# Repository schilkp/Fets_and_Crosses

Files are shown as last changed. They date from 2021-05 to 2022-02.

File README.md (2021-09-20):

# Fets and Crosses
### Philipp Schilk

An implementation of the classic Tic-Tac-Toe / Knots and Crosses game
built entirely from 2458 discrete transistors.

Why? *Because.*

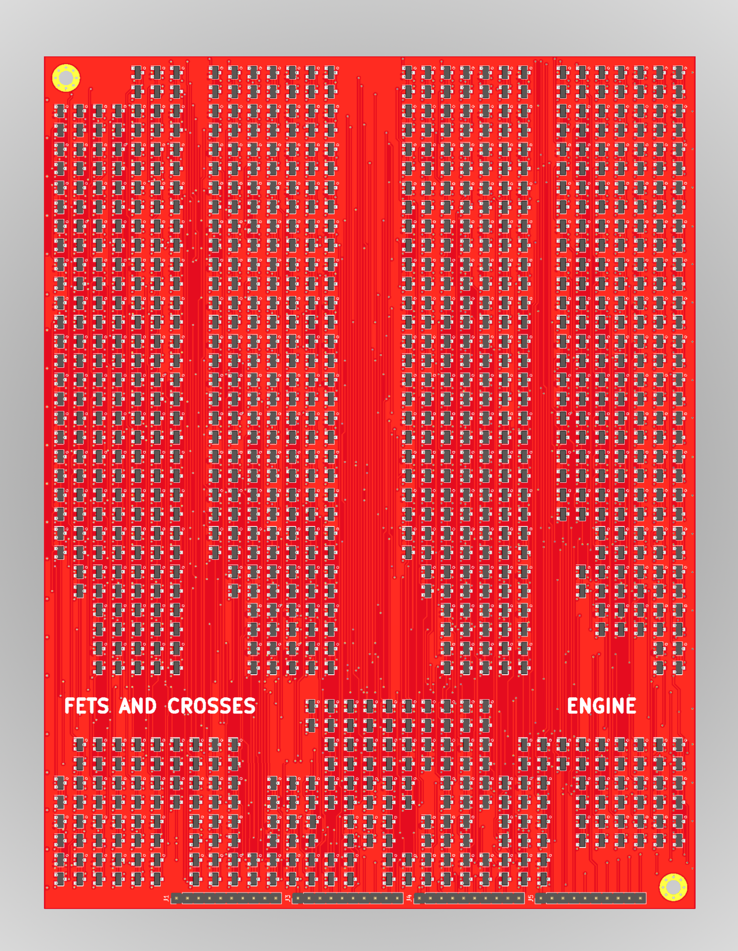
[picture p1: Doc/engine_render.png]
Engine Render


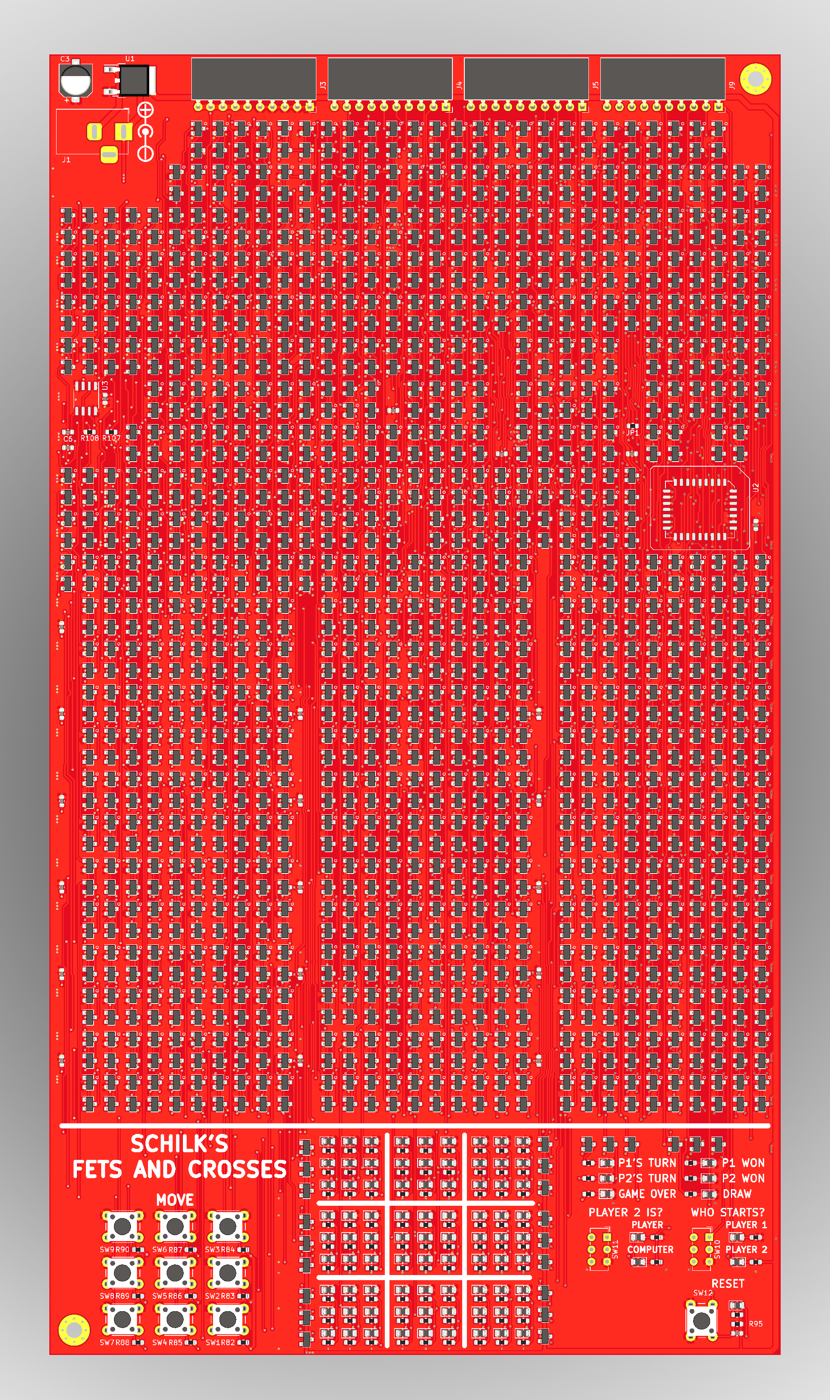
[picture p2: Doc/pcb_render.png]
PCB Render


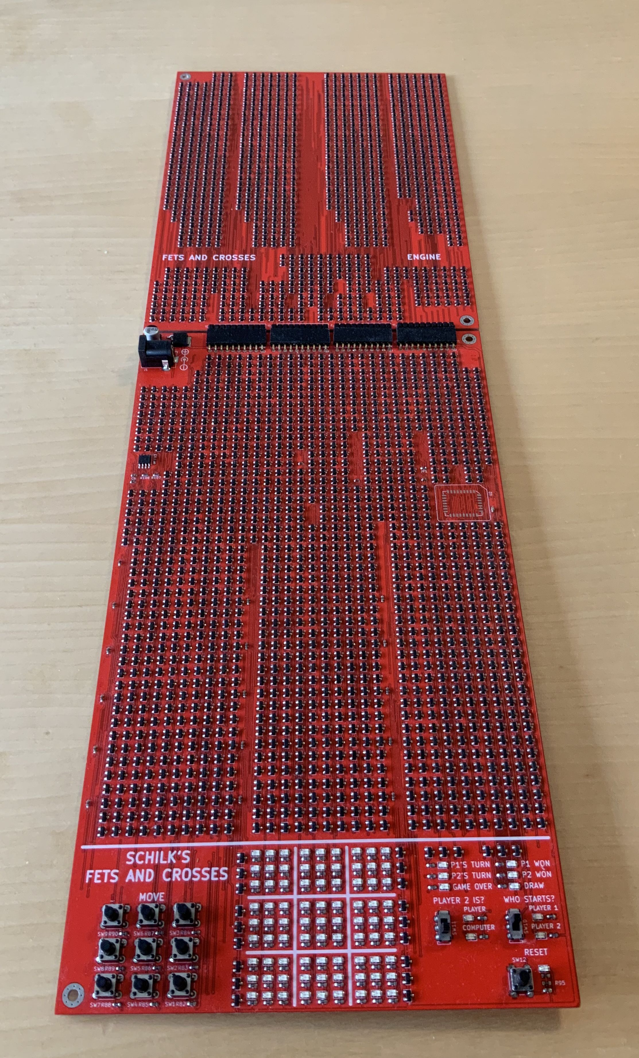
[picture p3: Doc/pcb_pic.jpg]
Full PCB Picture


## Features
- Players vs Player and Player vs Computer with engine fully implemented in transistors.
- Win-State and End-State detection
- Enforces game rules (prevents illegal moves)
- Shiny LEDs

## Release & Schematic viewing
See [Github releases](https://wwww.github.com/TheSchilk/Fets_and_Crosses/releases/) for all production files, schematics, etc...

Although the schematic is included in PDF form, it is recommended to view the schematic in KiCad directly.

## Implementation Details

All logic implemented in standard CMOS logic using discrete transistors.

The engine opponent is also implemented in logic on a seperate PCB, but can be substituted
with a ROM IC on the main IC.

JP1 has to be added when using the ROM IC, and removed when using the engine PCB.

## Overview

**Logisim:**  
	Logic Simulation.
	Download LogiSim at [cburch.com](http://www.cburch.com/logisim/).  
	
**Scripts:**  
	Various python scripts to test different engine designs and generate ROM contents.  

**ROM:**  
	Generated ROM files.  
	
**ECAD:**  
    All KiCad projects and production files.  
    
## Other Links
[Construction Timelapse](https://www.youtube.com/watch?v=Lz2p190qZ2Q)

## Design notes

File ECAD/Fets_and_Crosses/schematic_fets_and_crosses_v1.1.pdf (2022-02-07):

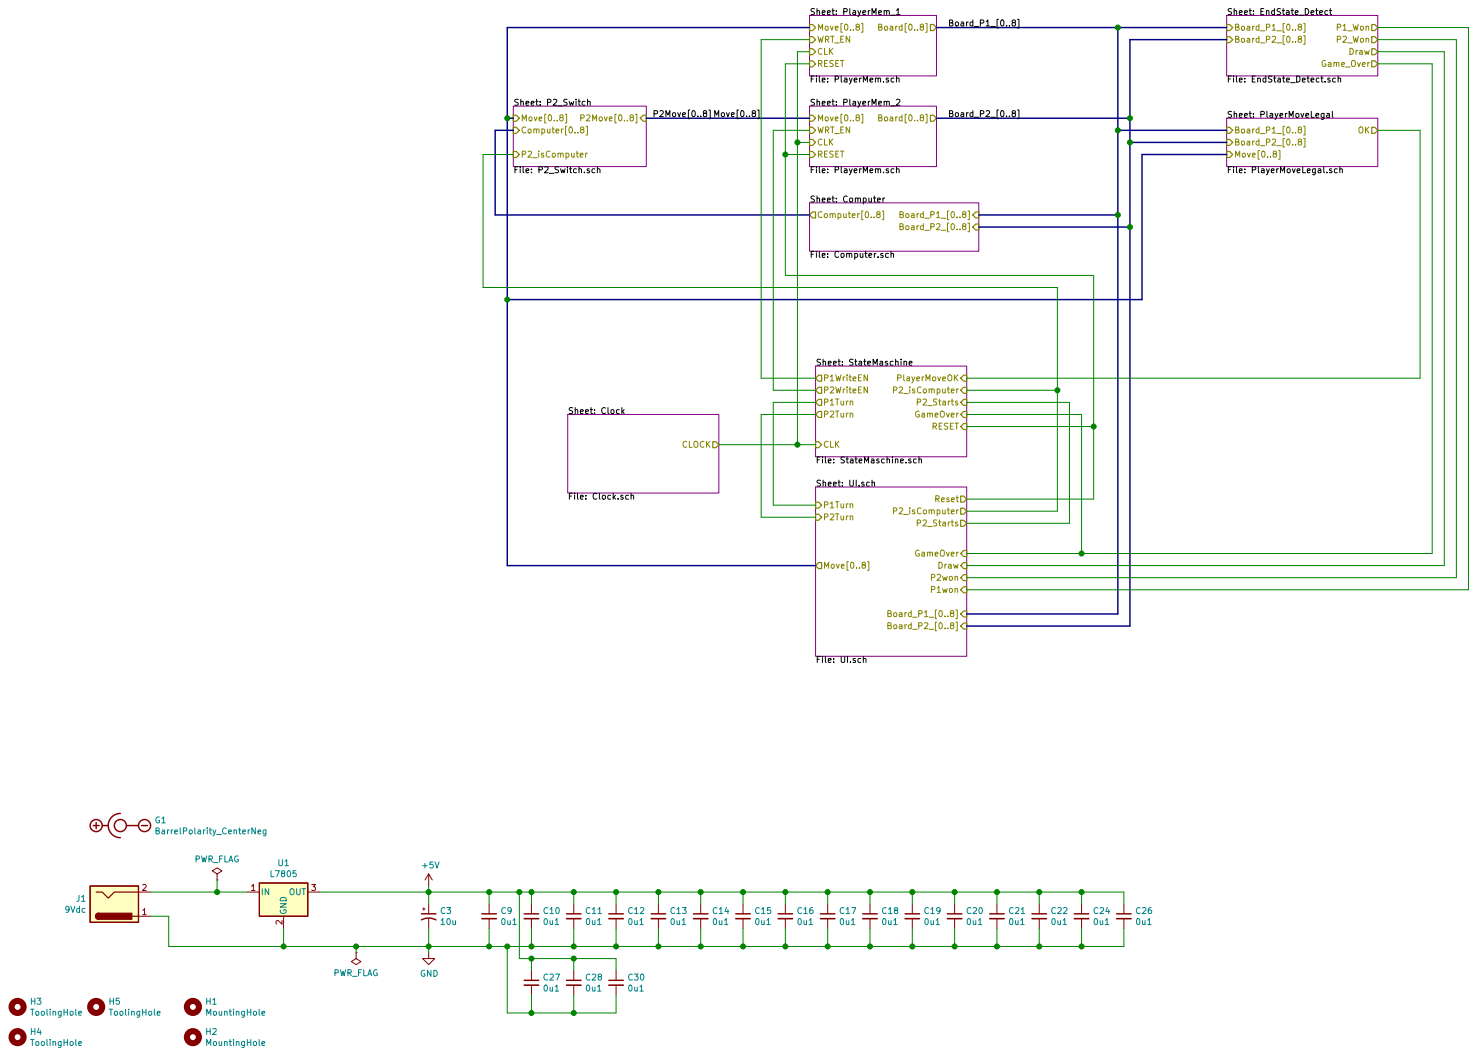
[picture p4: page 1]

Sheet: PlayerMem_1
Board_P2_[0..8] Sheet: StateMaschine File: StateMaschine.schPlayerMoveOK

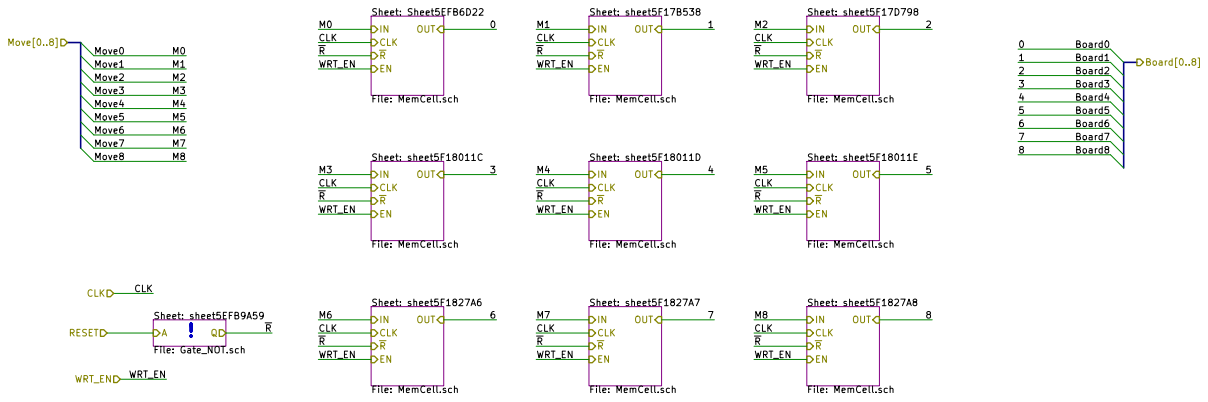
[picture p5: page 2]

Sheet: Sheet5EFB6D22 File: MemCell.sch

Sheet: sheet5F17B538 File: MemCell.sch
CLK CLK WRT_EN

Sheet: sheet5F17D798 File: MemCell.sch

Sheet: sheet5F1827A6 File: MemCell.sch

Sheet: sheet5F1827A7 File: MemCell.sch

Sheet: sheet5F1827A8 File: MemCell.sch

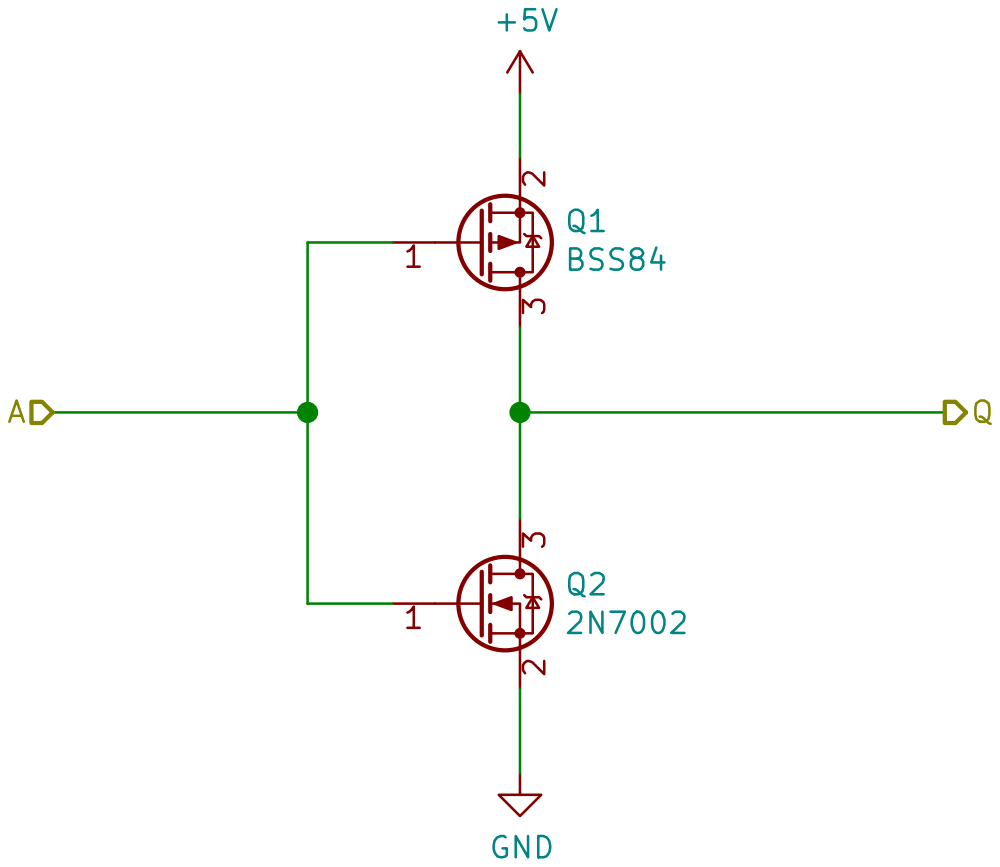
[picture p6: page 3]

Sheet: sheet5F46F774 File: Gate_NAND2in.sch Q AB

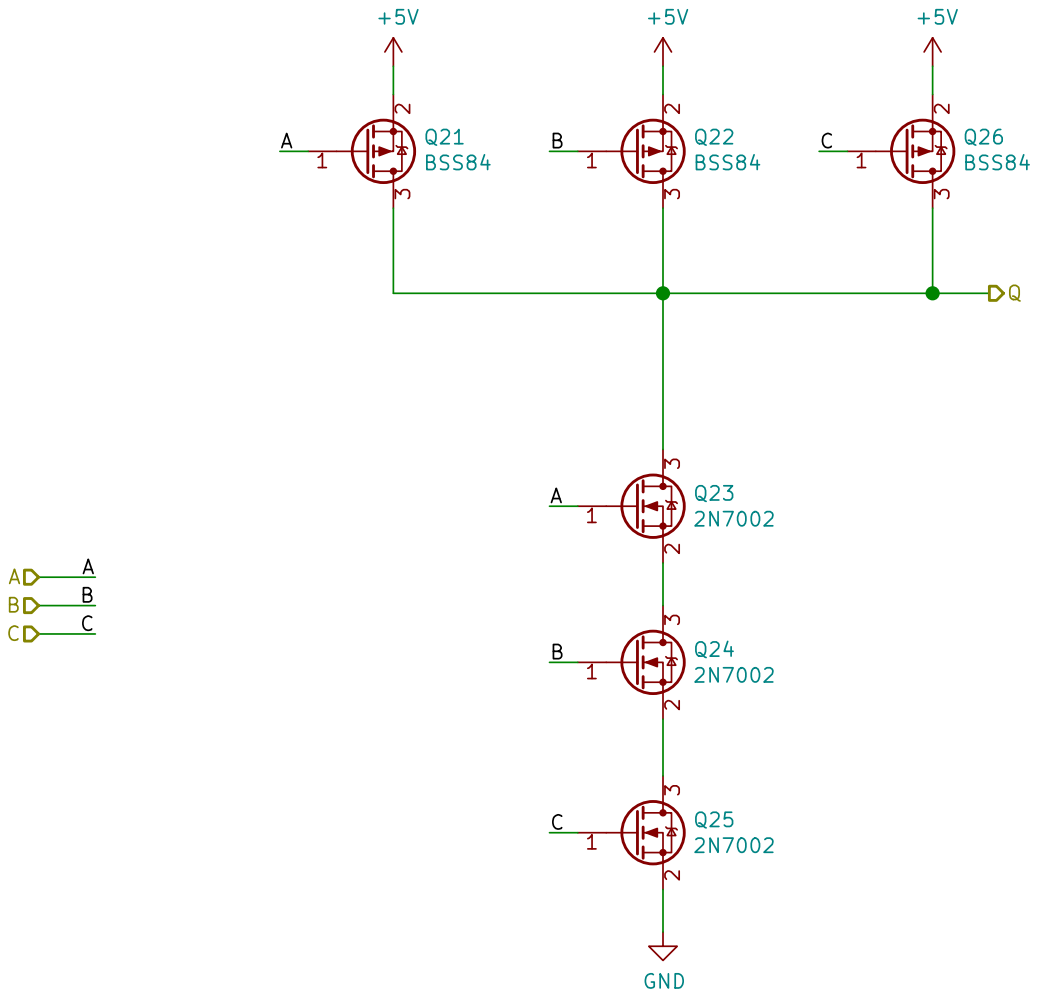
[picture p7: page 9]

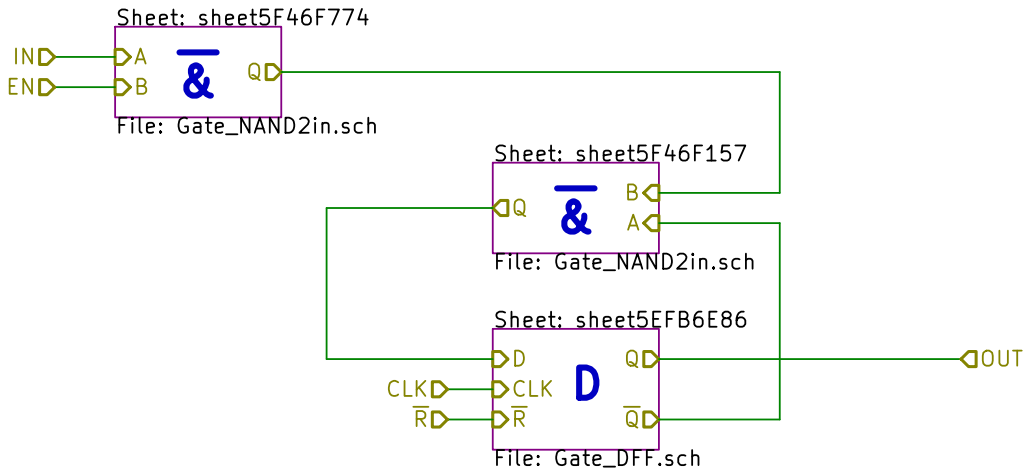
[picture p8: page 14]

Sheet: sheet5F46F774 File: Gate_NAND2in.sch Q AB

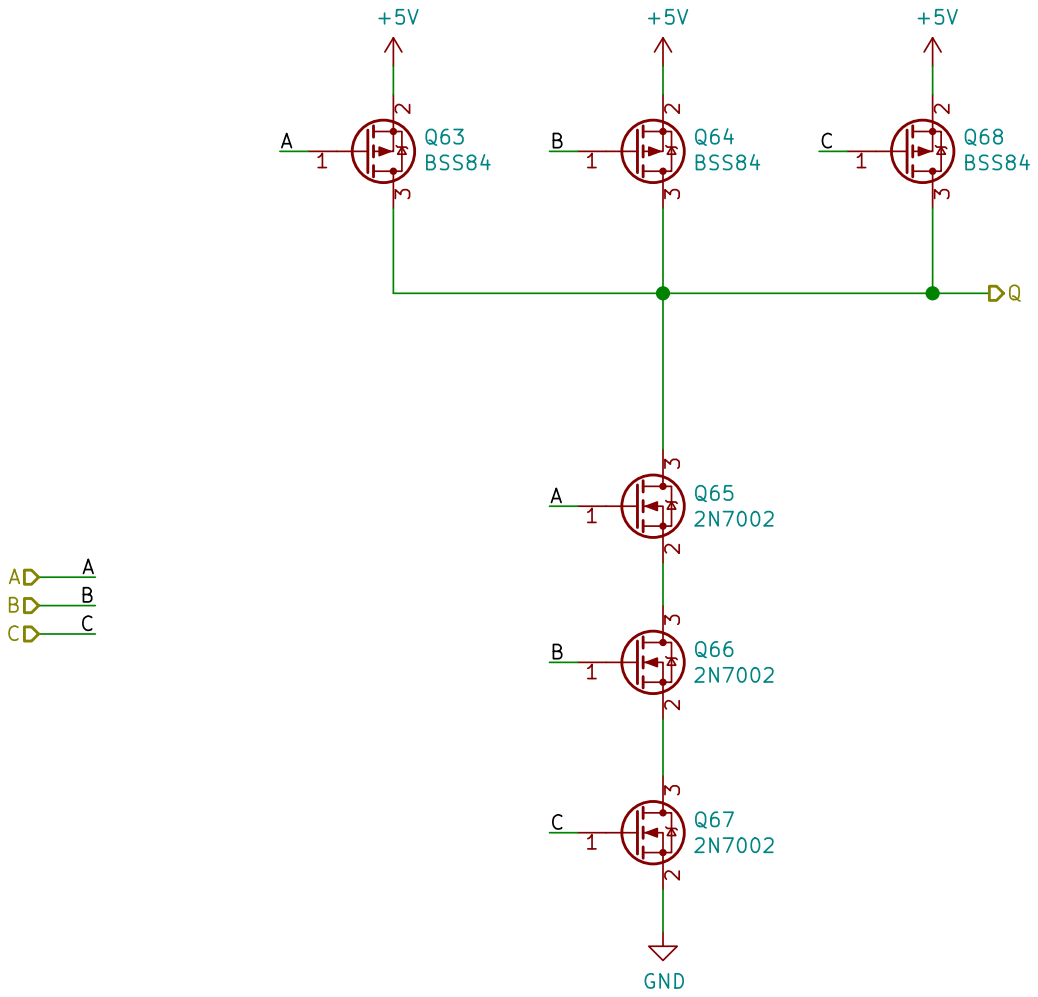
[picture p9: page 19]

Sheet: sheet5F46F774 File: Gate_NAND2in.sch Q AB

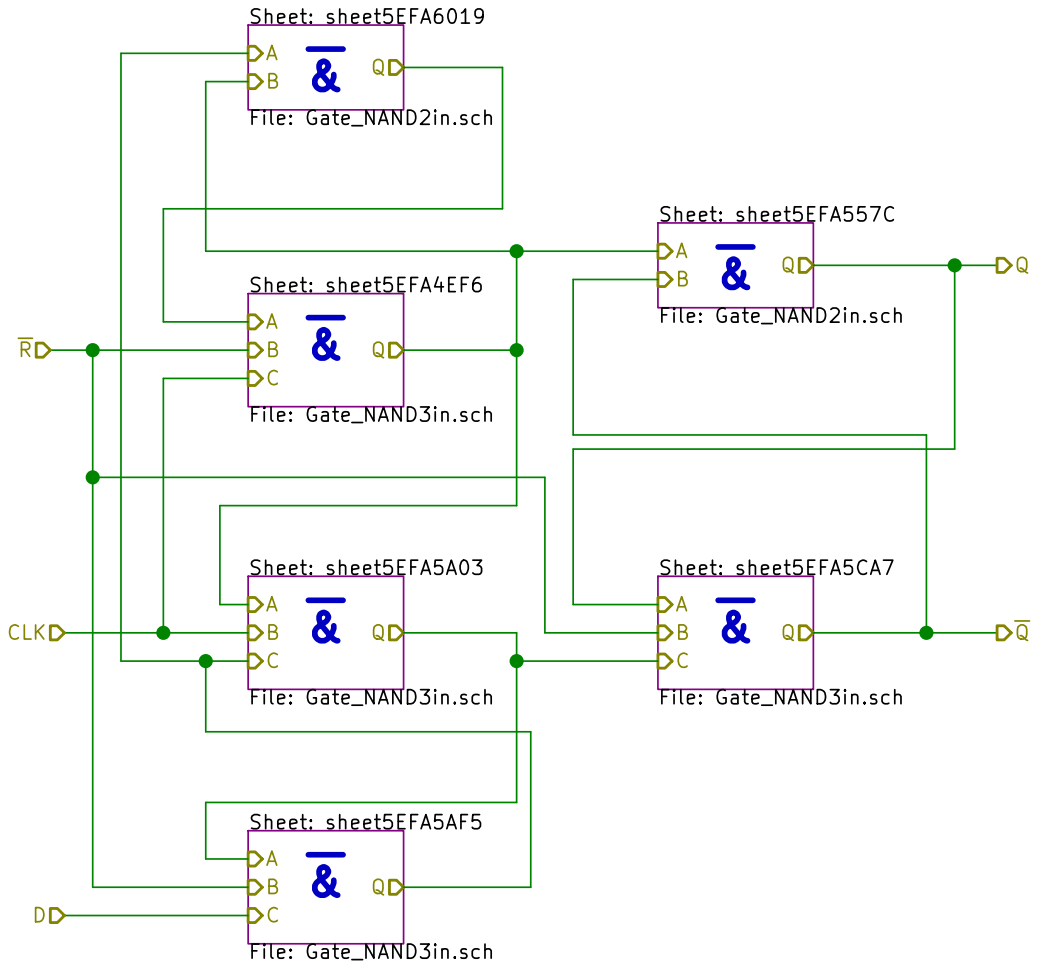
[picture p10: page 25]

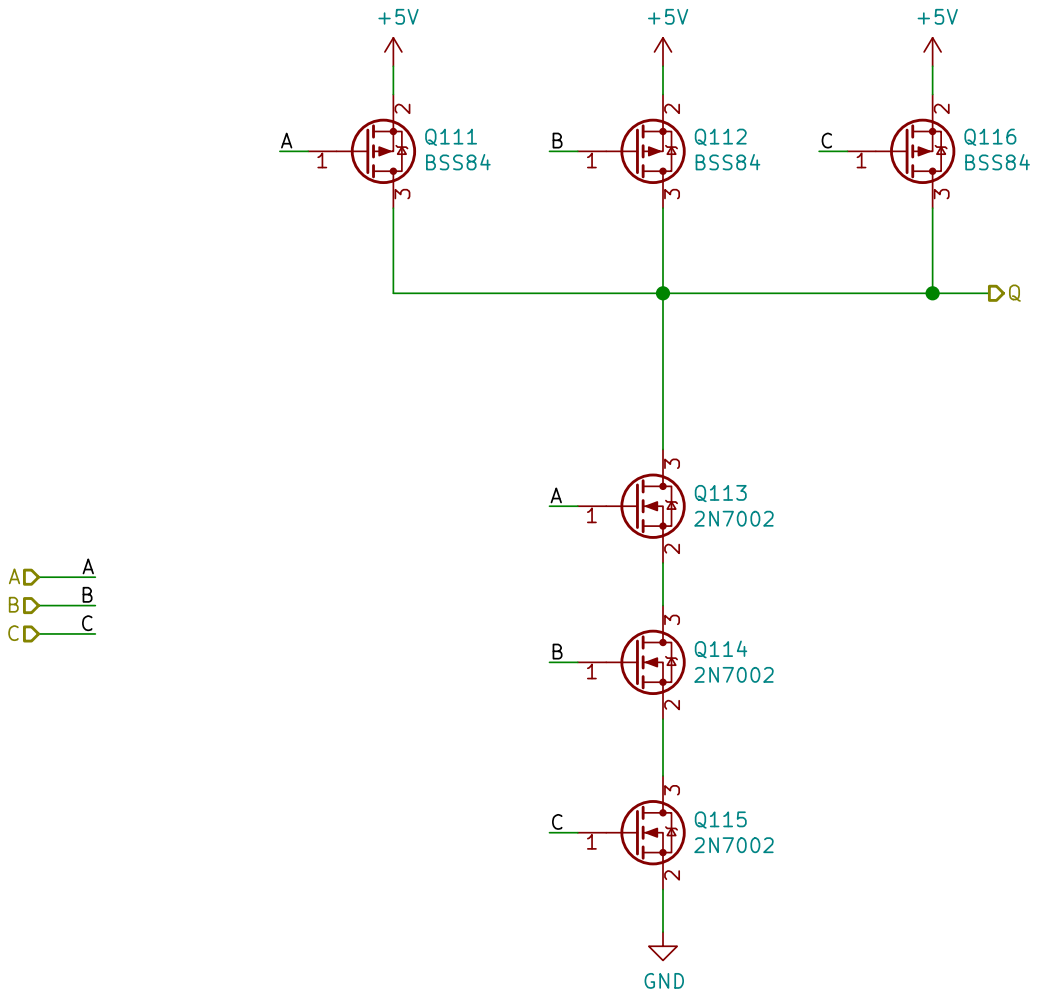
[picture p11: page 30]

Sheet: sheet5F46F774 File: Gate_NAND2in.sch Q AB

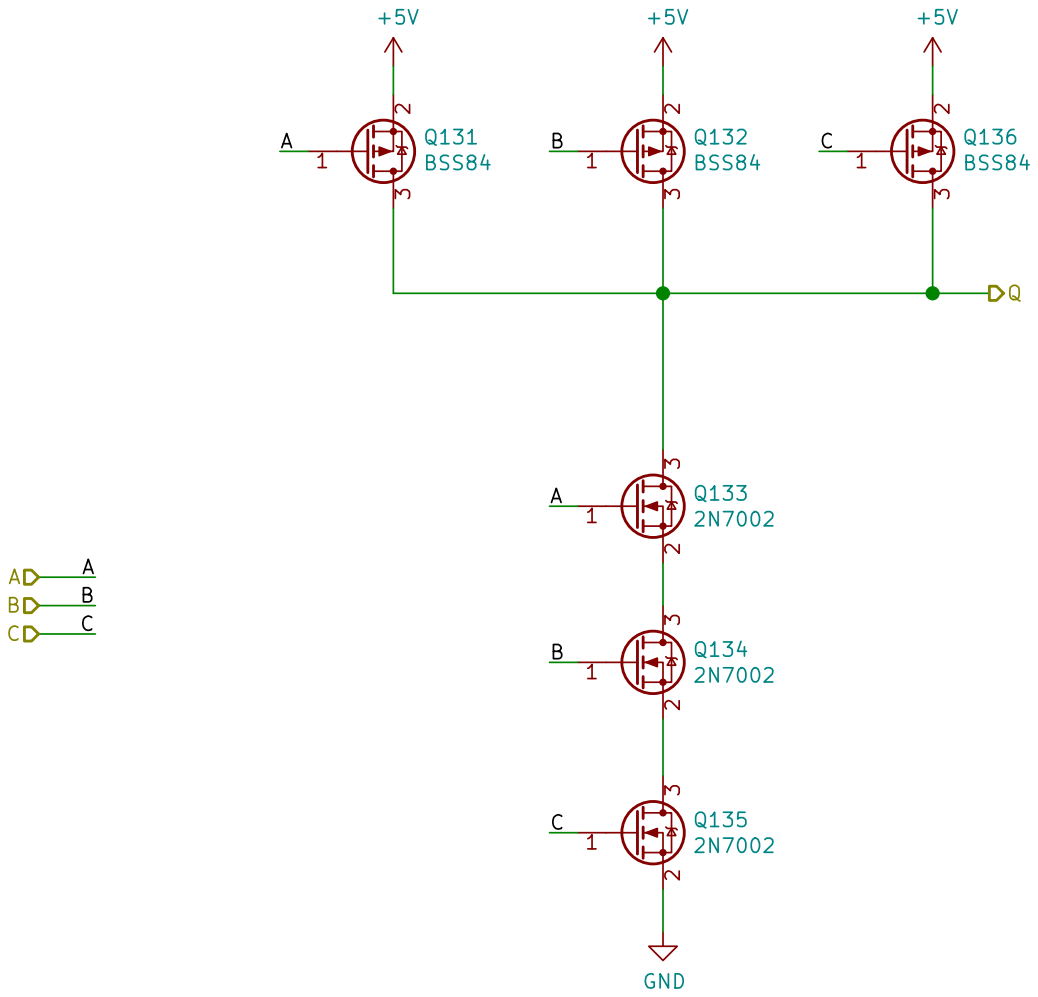
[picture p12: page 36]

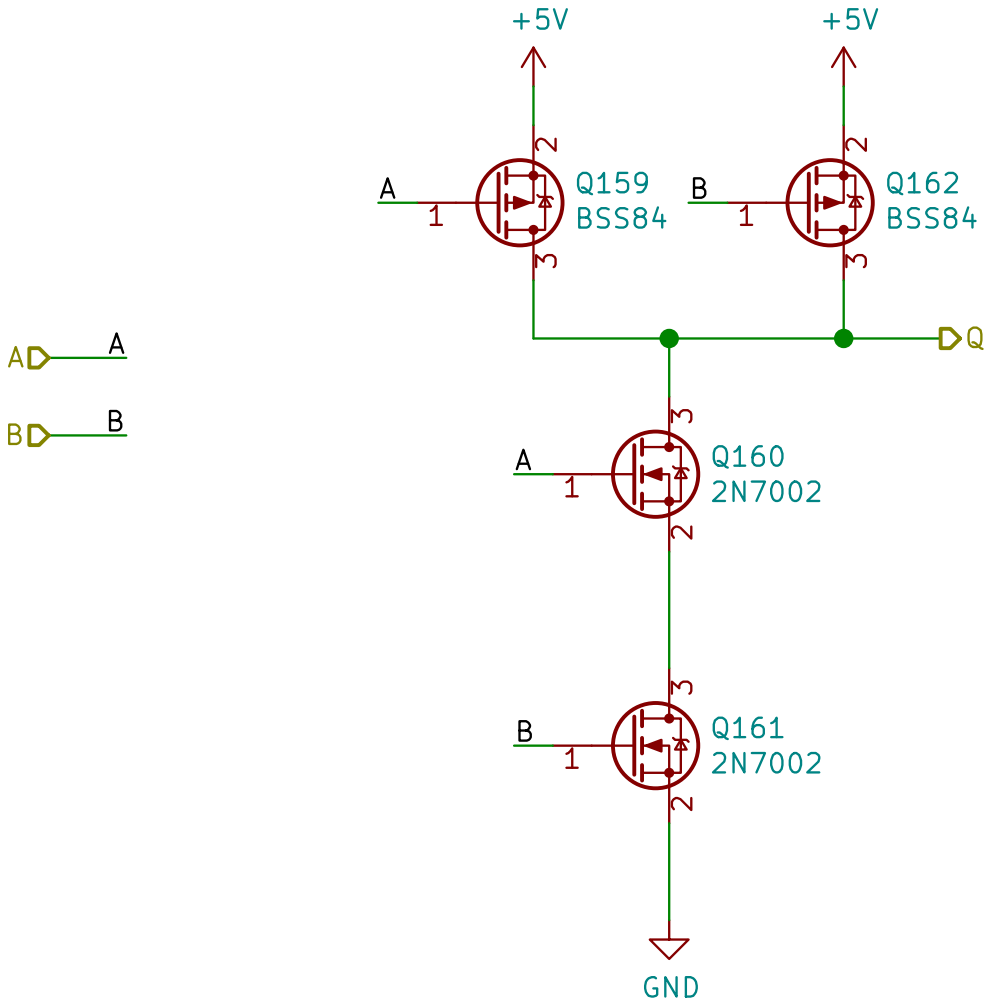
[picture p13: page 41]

Sheet: sheet5F46F774 File: Gate_NAND2in.sch Q AB

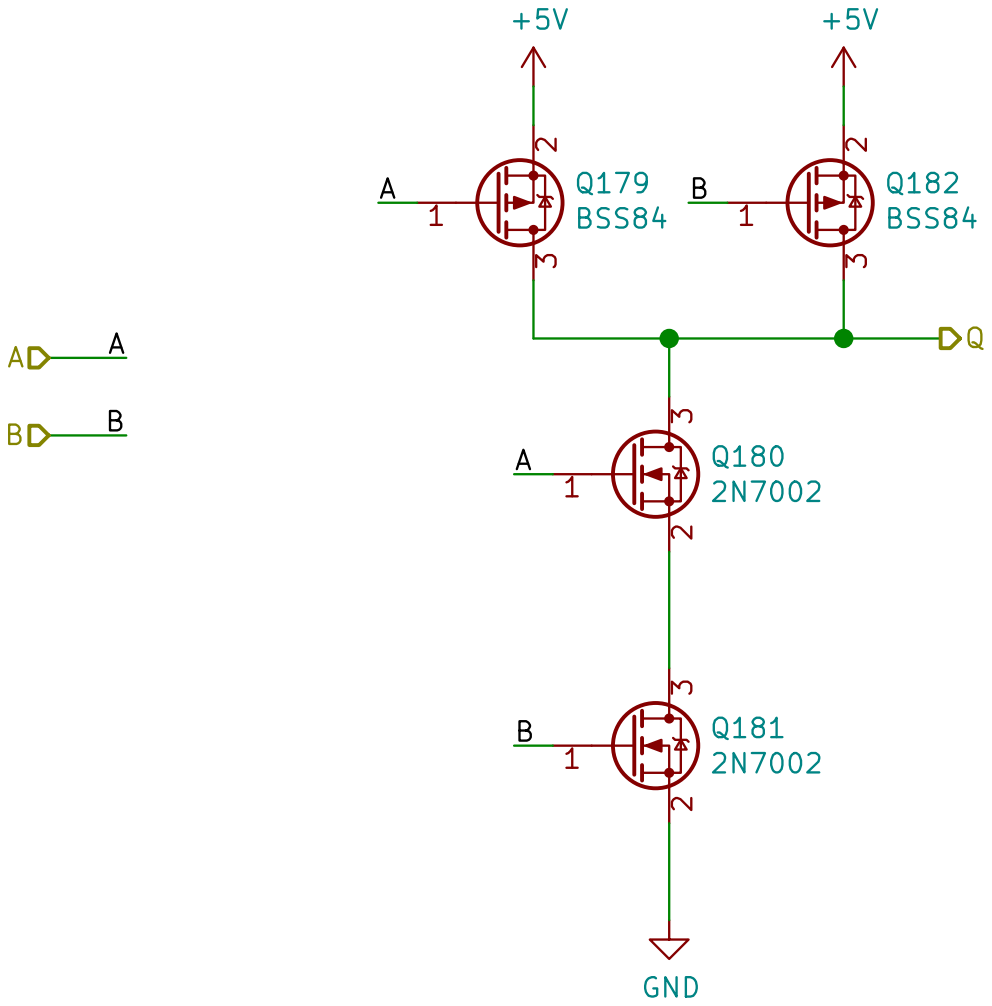
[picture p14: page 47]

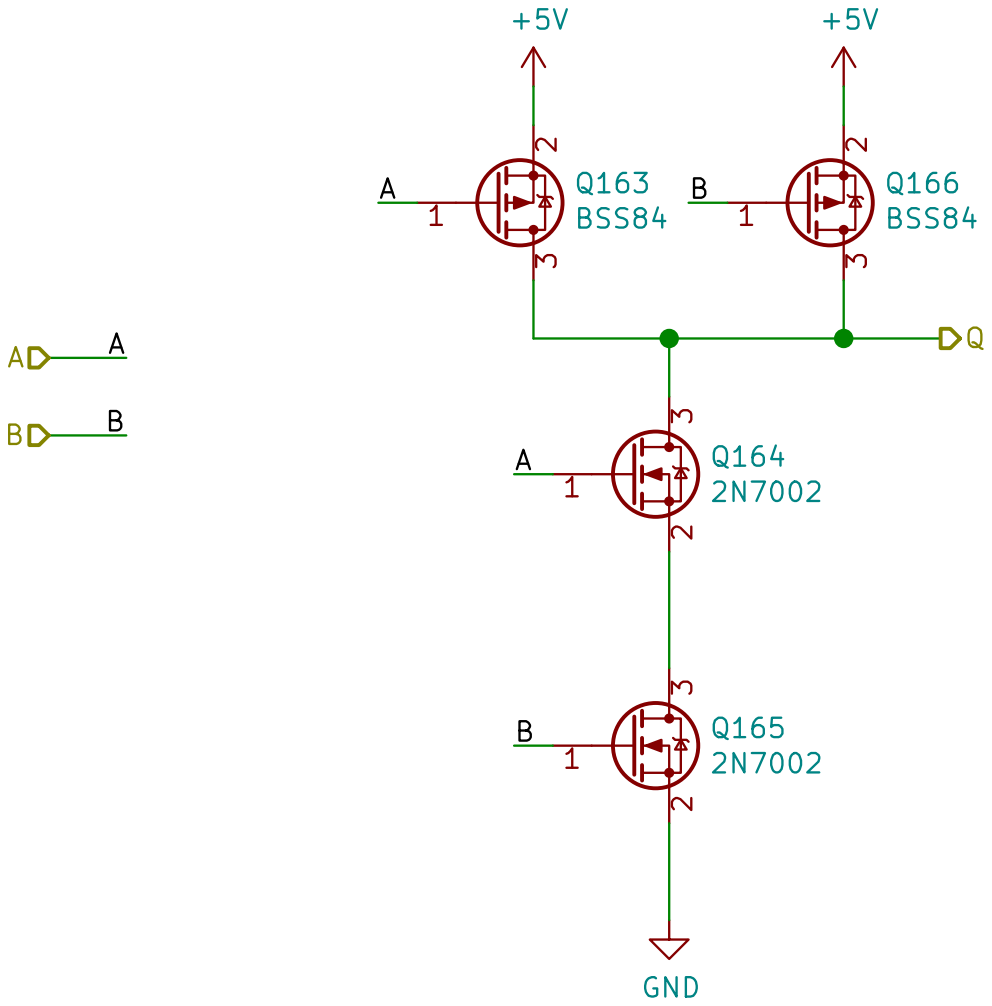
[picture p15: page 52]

Sheet: sheet5F46F774 File: Gate_NAND2in.sch Q AB

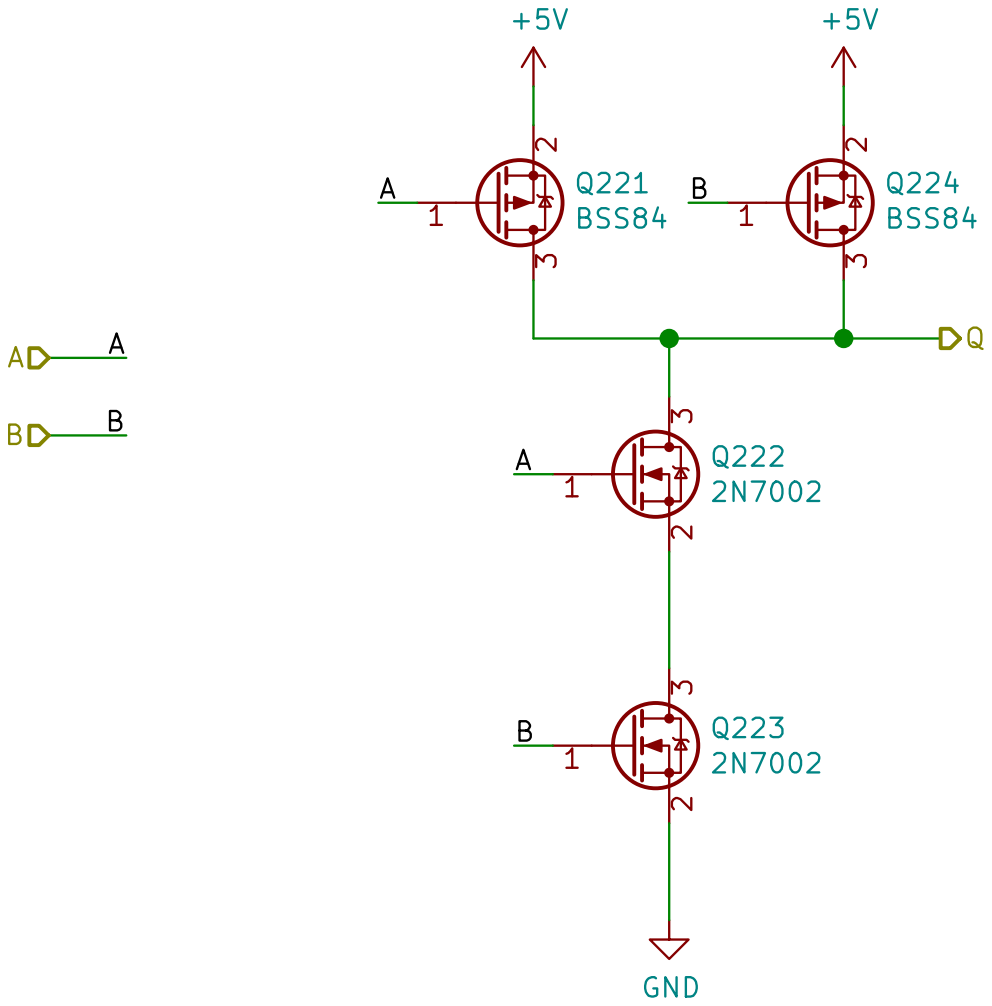
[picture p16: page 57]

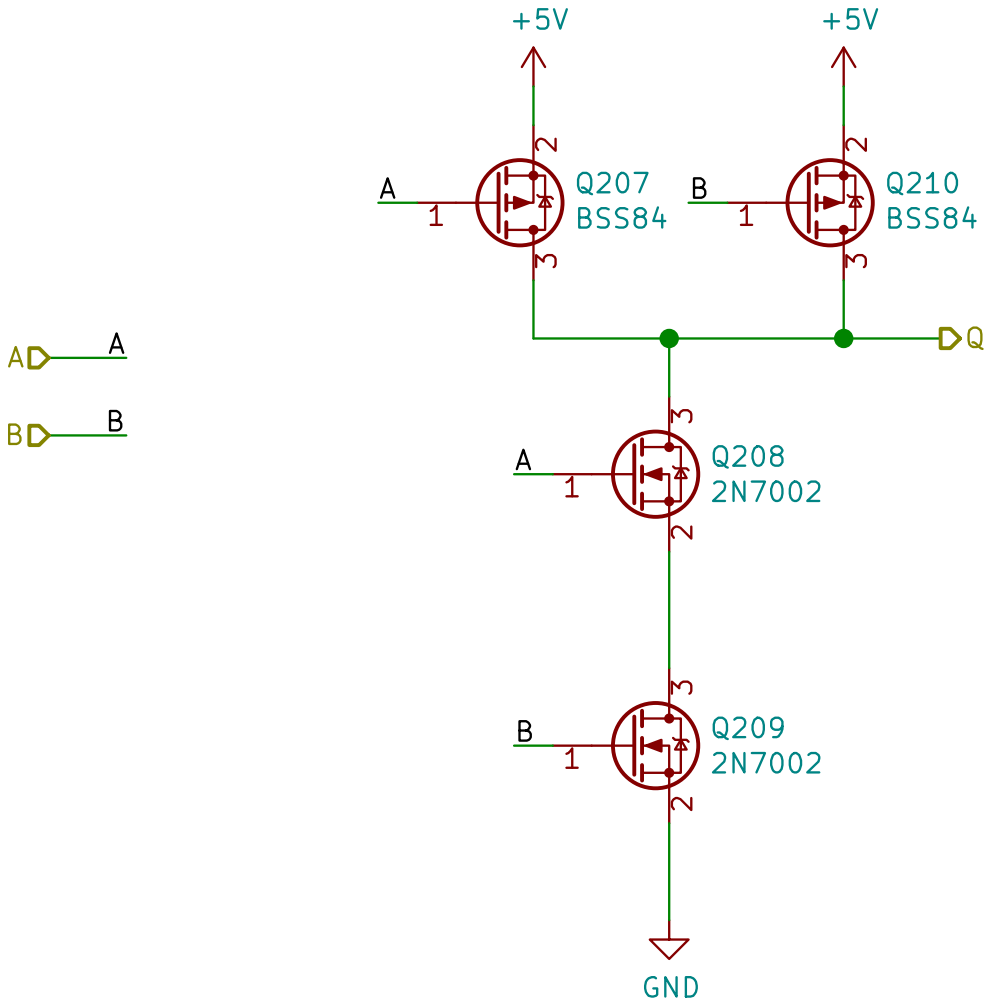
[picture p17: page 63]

Sheet: sheet5F46F774 File: Gate_NAND2in.sch Q AB

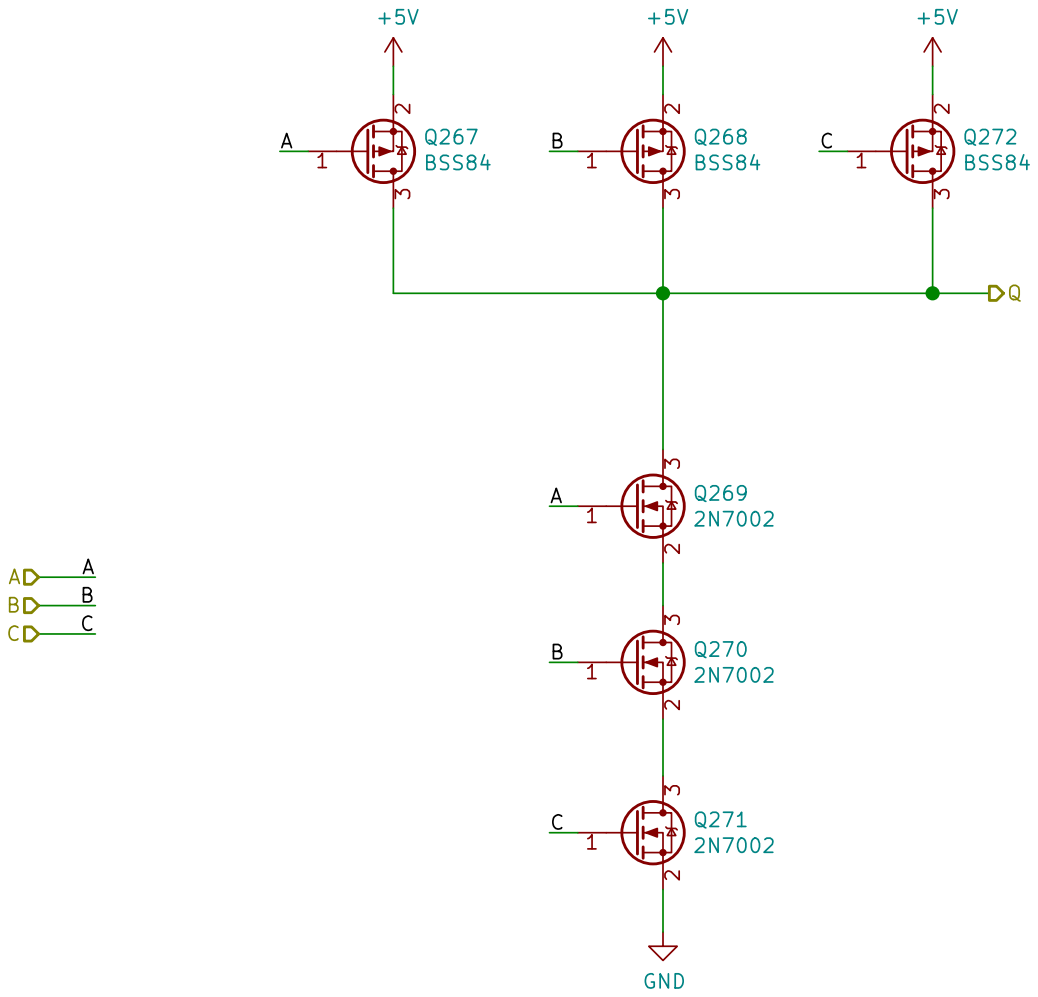
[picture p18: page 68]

Sheet: sheet5F46F774 File: Gate_NAND2in.sch Q AB

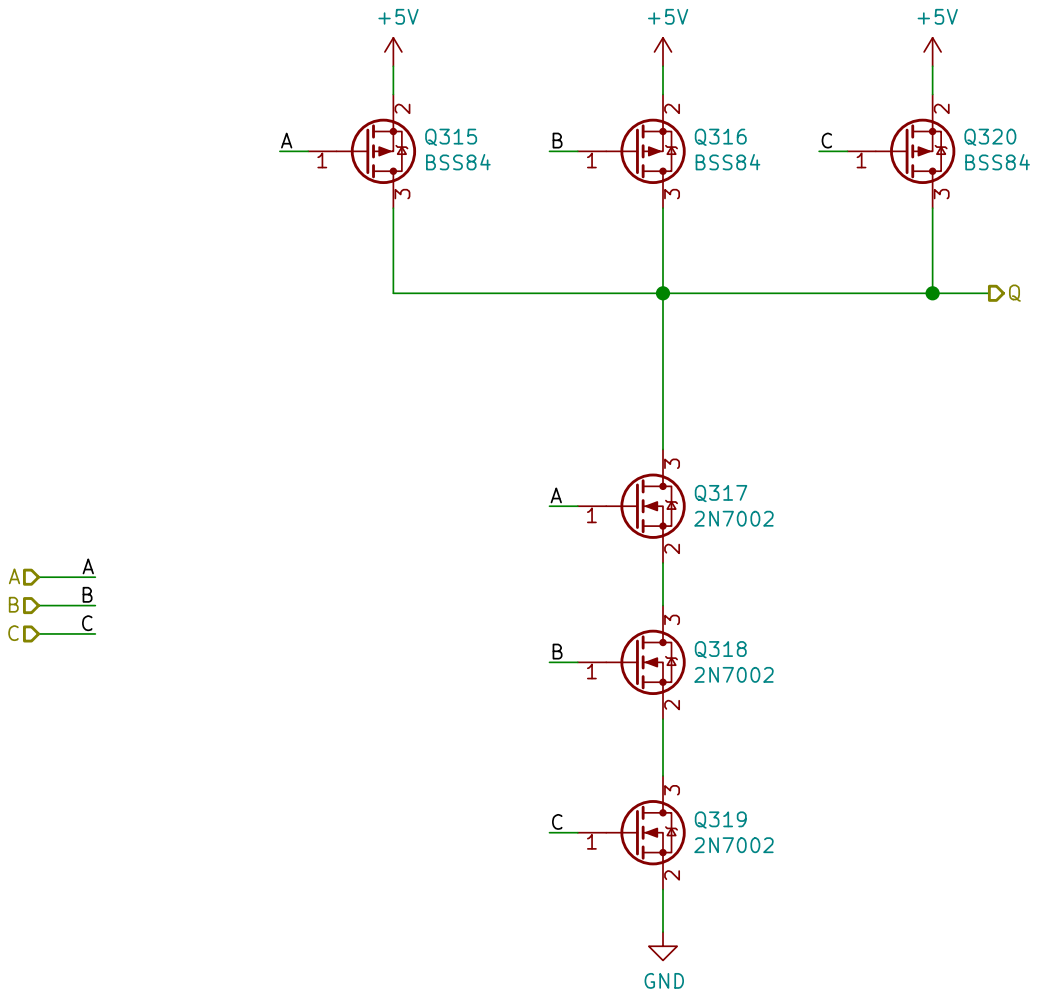
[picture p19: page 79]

Sheet: sheet5F46F774 File: Gate_NAND2in.sch Q AB

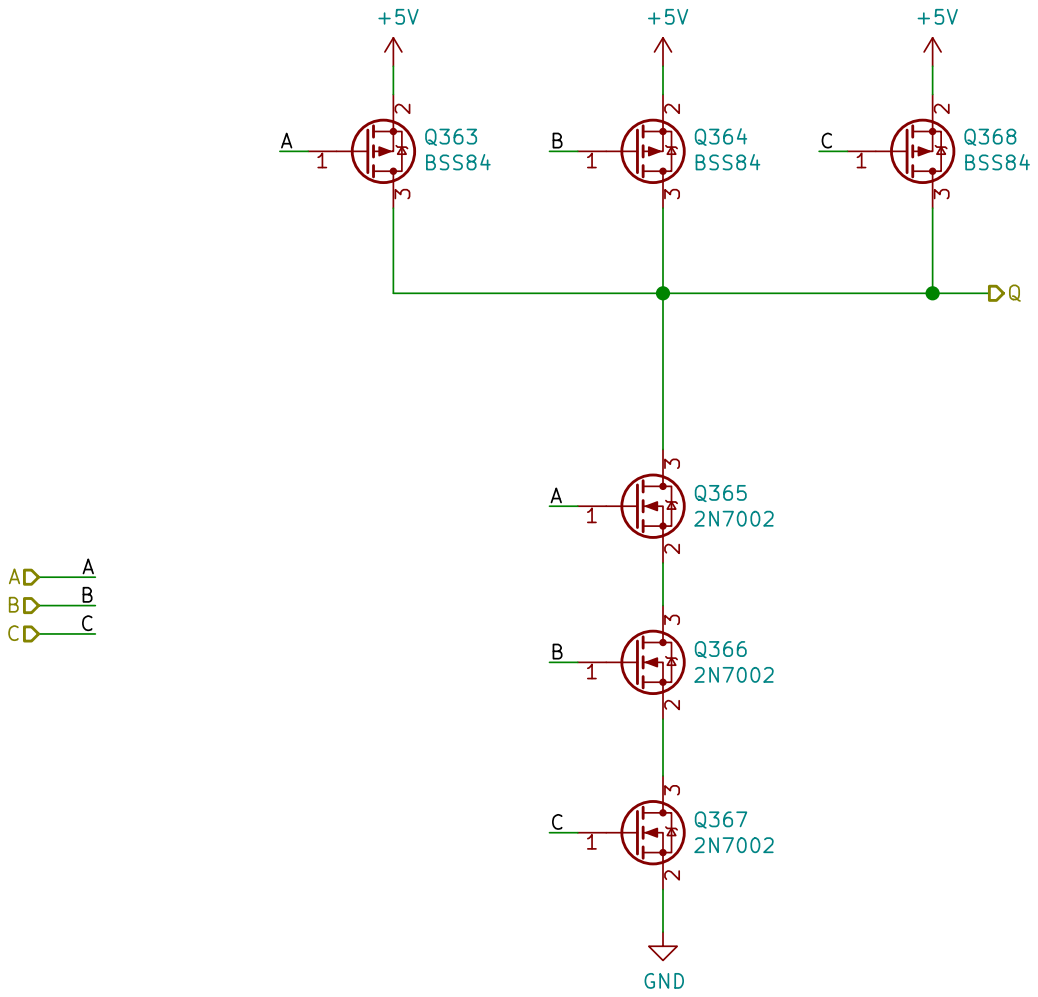
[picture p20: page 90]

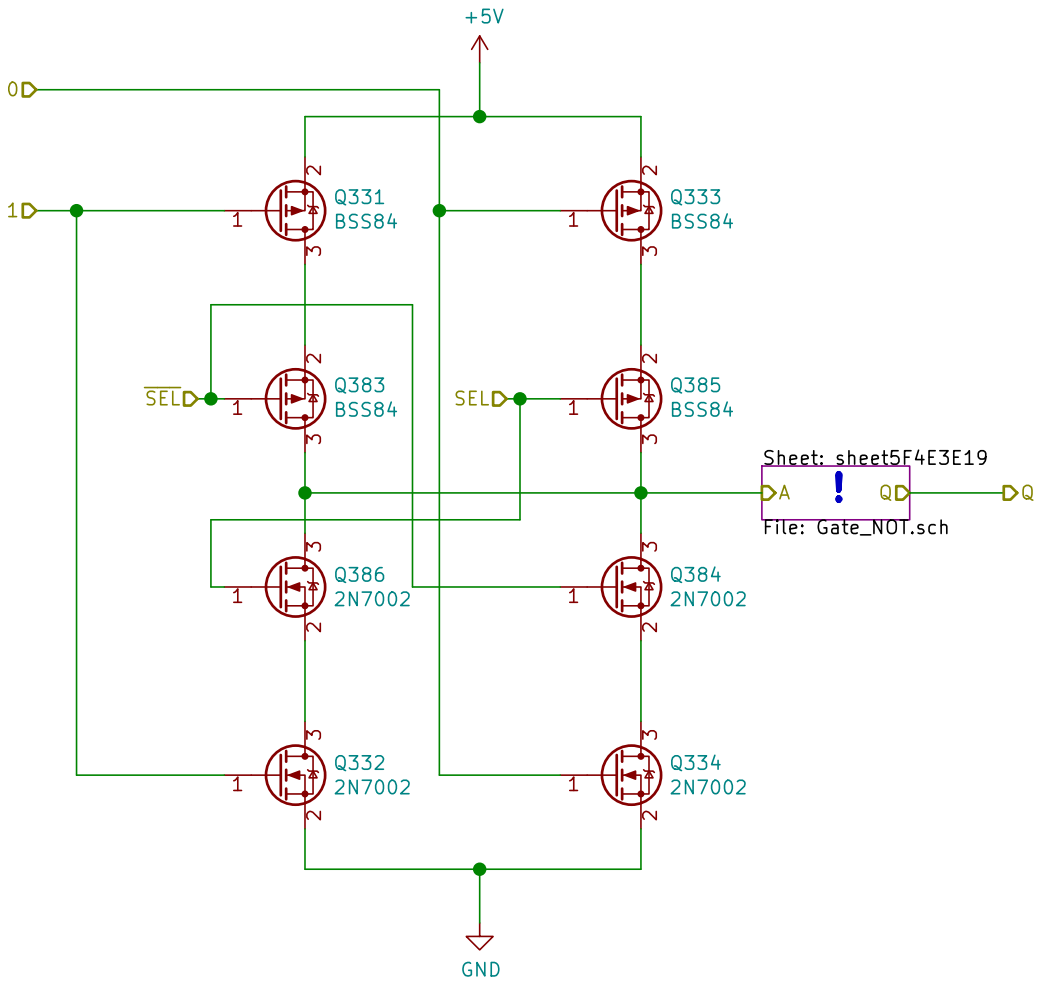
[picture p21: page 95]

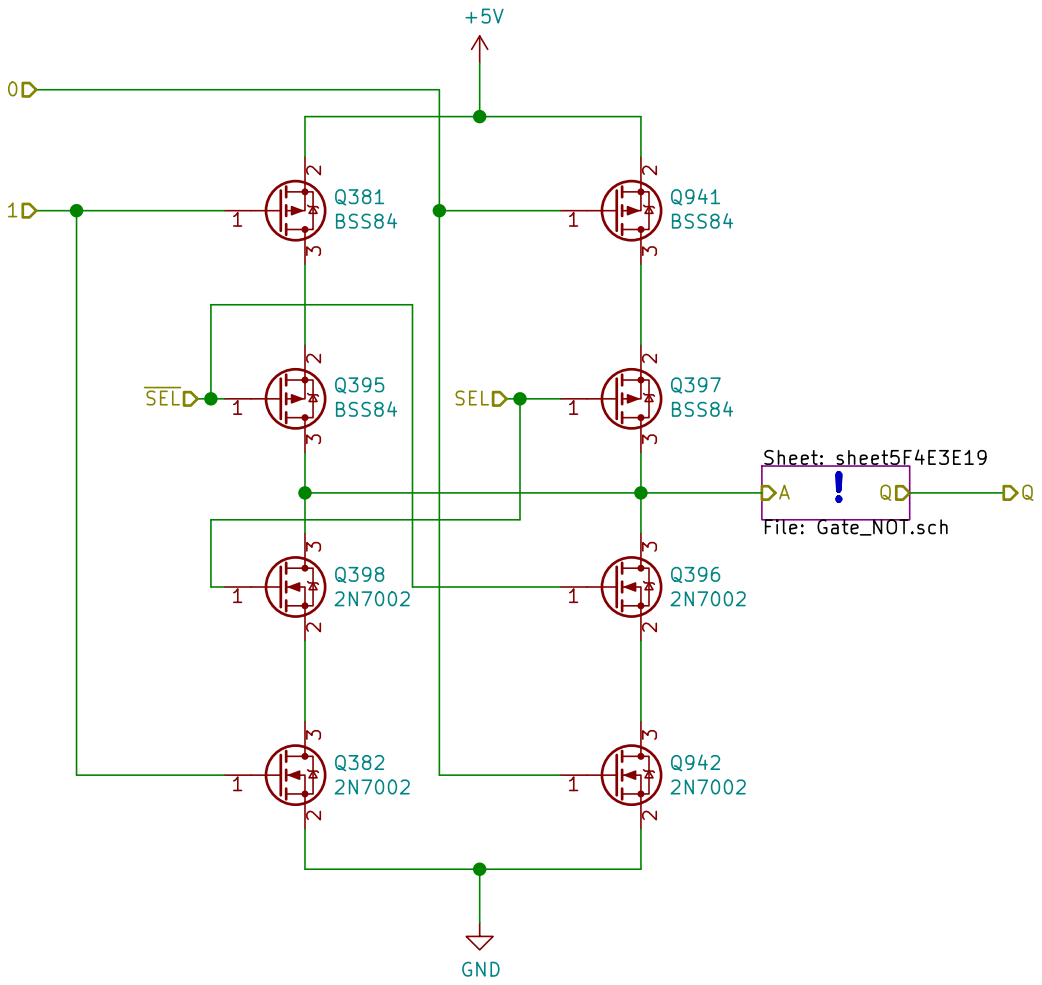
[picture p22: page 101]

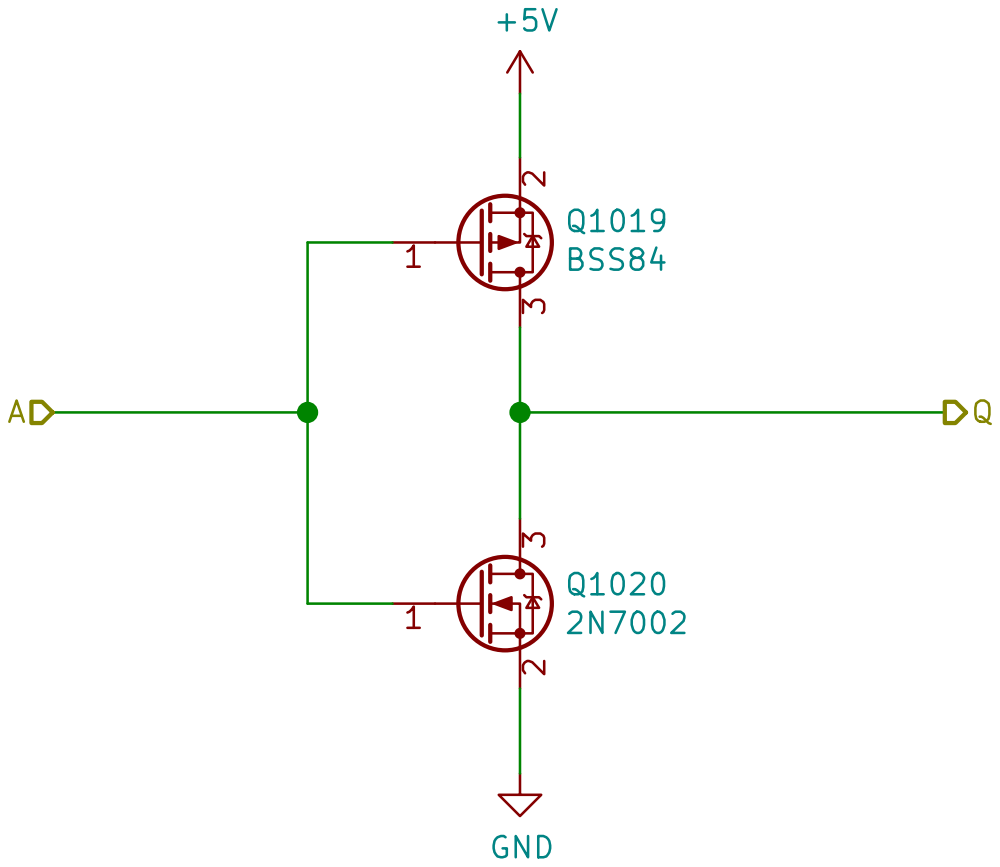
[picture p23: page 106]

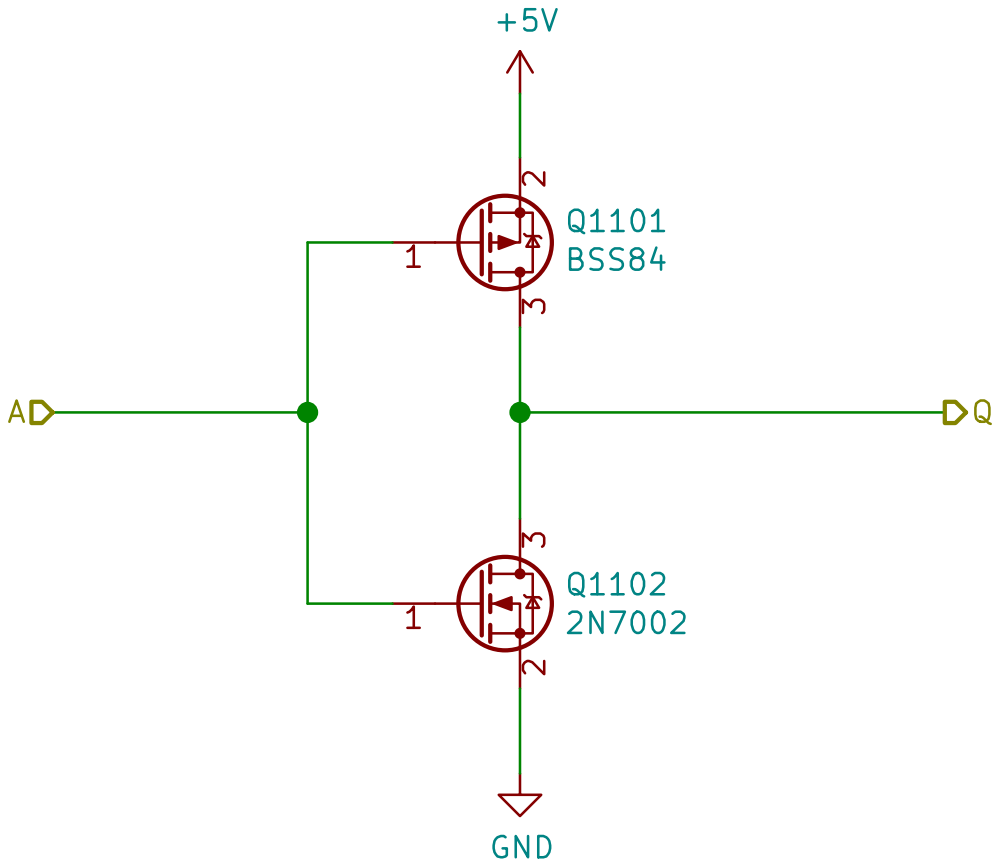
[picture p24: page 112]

Sheet: sheet5ED25FC7 File: Gate_NOR3in.sch Q ABC

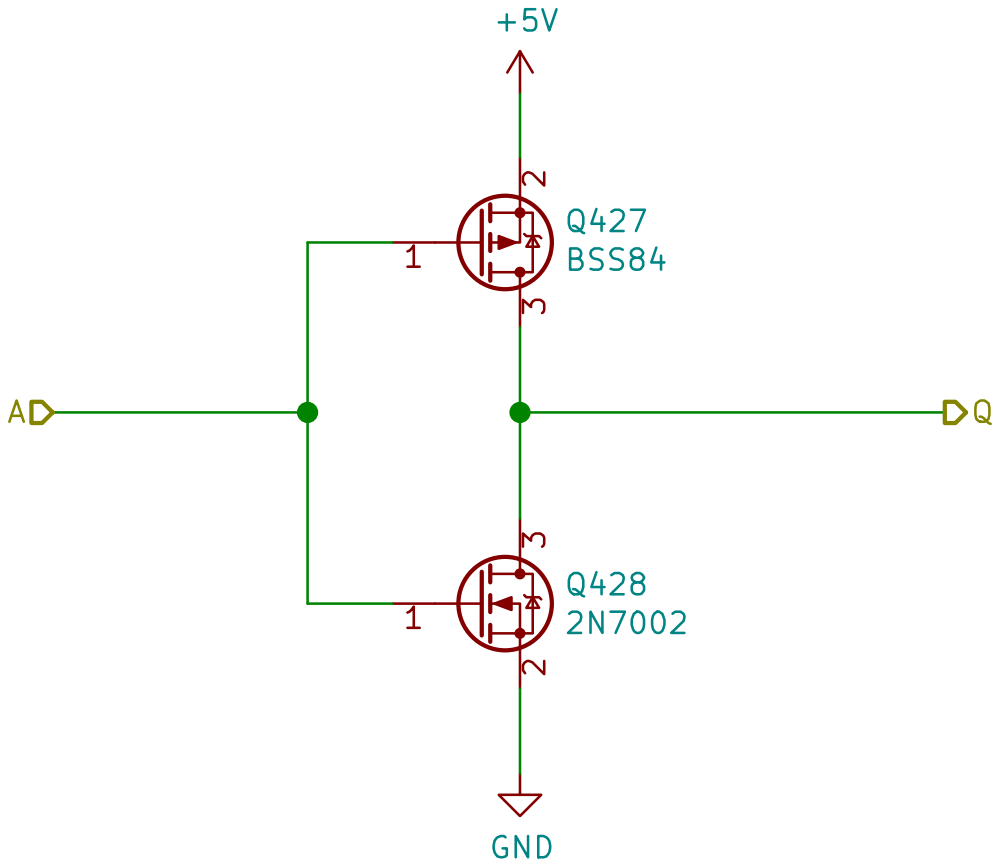
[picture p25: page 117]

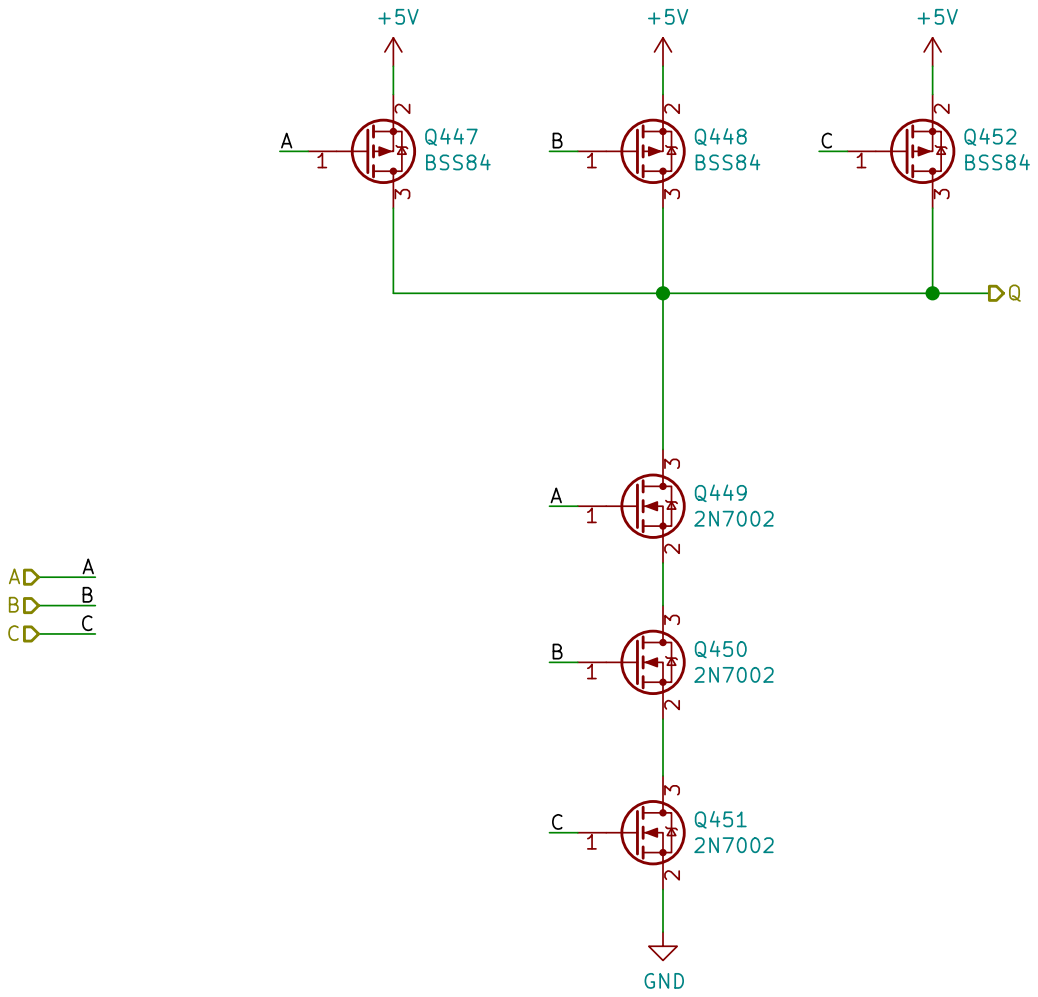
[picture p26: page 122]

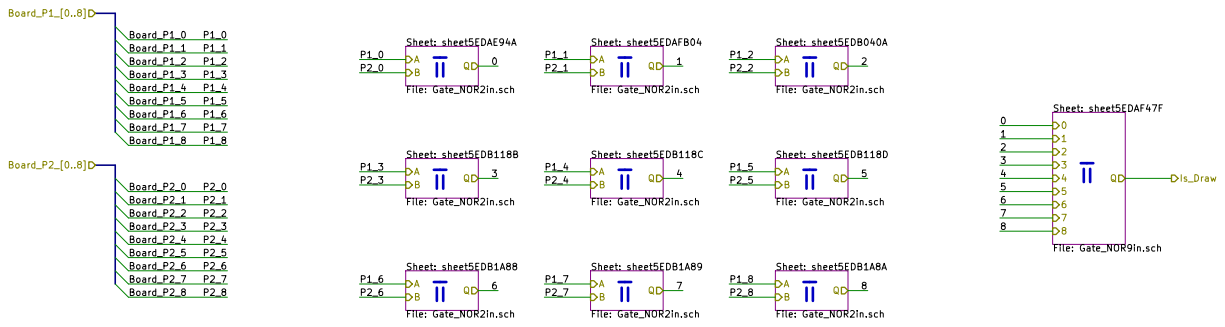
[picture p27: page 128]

Sheet: sheet5EDAFB04 File: Gate_NOR2in.sch Q AB

Sheet: sheet5EDB1A88 File: Gate_NOR2in.sch Q AB

Sheet: sheet5EDB1A89 File: Gate_NOR2in.sch Q AB
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

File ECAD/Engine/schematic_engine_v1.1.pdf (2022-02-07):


Sheet: sheet60E2C560 File: Gate_OR8in.sch Q 1 2 4 5 6 7


















Sheet: sheet60756855 File: Gate_NOR2in.sch Q AB A


Sheet: sheet60756855 File: Gate_NOR2in.sch Q AB A


Sheet: sheet60756855 File: Gate_NOR2in.sch Q AB A


Sheet: sheet60756855 File: Gate_NOR2in.sch Q AB A


Sheet: sheet60756855 File: Gate_NOR2in.sch Q AB A


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

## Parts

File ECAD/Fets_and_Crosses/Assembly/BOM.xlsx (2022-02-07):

Comment | Designator | Footprint | LCSC
10n | C6 | Capacitor_SMD:C_0603_1608Metric | C57112
0u1 | C1,C5,C7,C8,C9,C10,C11,C12,C13,C14,C15,C16,C17,C18,C19,C20,C21,C22,C24,C26,C27,C28,C30 | LogicQ:C_0603_1608Metric_NOLBL | C14663
RED | D1,D3,D5,D7,D9,D10,D12,D14,D16,D18,D19,D21,D23,D25,D27,D28,D30,D32,D34,D36,D37,D39,D41,D43,D45,D46,D48,D50,D52,D54,D55,D57,D59,D61,D63,D64,D66,D68,D70,D72,D73,D75,D77,D79,D81,D83,D85,D86,D89,D93,D94,D96 | LogicQ:D_0805_2012Metric_NOLBL | C72037
GREEN | D2,D4,D6,D8,D11,D13,D15,D17,D20,D22,D24,D26,D29,D31,D33,D35,D38,D40,D42,D44,D47,D49,D51,D53,D56,D58,D60,D62,D65,D67,D69,D71,D74,D76,D78,D80,D82,D84,D92,D95 | LogicQ:D_0805_2012Metric_NOLBL | C84260
BSS84 | Q1,Q3,Q5,Q6,Q10,Q11,Q14,Q15,Q16,Q20,Q21,Q22,Q26,Q27,Q28,Q32,Q33,Q36,Q38,Q39,Q42,Q43,Q46,Q47,Q48,Q52,Q53,Q56,Q57,Q58,Q62,Q63,Q64,Q68,Q69,Q70,Q74,Q75,Q78,Q79,Q82,Q83,Q86,Q87,Q89,Q90,Q94,Q95,Q98,Q99,Q100,Q104,Q105,Q106,Q110,Q111,Q112,Q116,Q117,Q120,Q122,Q123,Q126,Q127,Q130,Q131,Q132,Q136,Q137,Q140,Q141,Q142,Q146,Q147,Q148,Q152,Q153,Q154,Q158,Q159,Q162,Q163,Q166,Q167,Q170,Q171,Q173,Q174,Q178,Q179,Q182,Q183,Q184,Q188,Q189,Q190,Q194,Q195,Q196,Q200,Q201,Q204,Q206,Q207,Q210,Q211,Q214,Q215,Q216,Q220,Q221,Q224,Q225,Q226,Q230,Q231,Q232,Q236,Q237,Q238,Q242,Q243,Q246,Q247,Q250,Q251,Q254,Q255,Q257,Q258,Q262,Q263,Q266,Q267,Q268,Q272,Q273,Q274,Q278,Q279,Q280,Q284,Q285,Q288,Q290,Q291,Q294,Q295,Q298,Q299,Q300,Q304,Q305,Q308,Q309,Q310,Q314,Q315,Q316,Q320,Q321,Q322,Q326,Q327,Q330,Q331,Q333,Q335,Q337,Q339,Q341,Q342,Q346,Q347,Q350,Q351,Q352,Q356,Q357,Q358,Q362,Q363,Q364,Q368,Q369,Q372,Q373,Q375,Q377,Q379,Q381,Q383,Q385,Q387,Q389,Q391,Q393,Q395,Q397,Q399,Q401,Q403,Q405,Q407,Q409,Q411,Q413,Q415,Q417,Q419,Q423,Q424,Q425,Q427,Q429,Q430,Q434,Q435,Q436,Q440,Q441,Q442,Q446,Q447,Q448,Q452,Q453,Q454,Q458,Q459,Q460,Q464,Q465,Q466,Q470,Q471,Q472,Q476,Q477,Q478,Q481,Q482,Q483,Q487,Q488,Q489,Q494,Q495,Q497,Q498,Q499,Q503,Q504,Q505,Q509,Q510,Q511,Q516,Q517,Q520,Q521,Q524,Q525,Q528,Q529,Q532,Q533,Q536,Q537,Q540,Q541,Q544,Q545,Q547,Q548,Q552,Q553,Q554,Q558,Q559,Q560,Q564,Q565,Q566,Q570,Q571,Q572,Q576,Q577,Q578,Q582,Q583,Q584,Q588,Q589,Q590,Q594,Q595,Q596,Q599,Q600,Q601,Q605,Q606,Q607,Q611,Q612,Q616,Q617,Q618,Q6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 | LogicQ:SOT-23-P | C114481
2N7002 | Q2,Q4,Q7,Q8,Q9,Q12,Q13,Q17,Q18,Q19,Q23,Q24,Q25,Q29,Q30,Q31,Q34,Q35,Q37,Q40,Q41,Q44,Q45,Q49,Q50,Q51,Q54,Q55,Q59,Q60,Q61,Q65,Q66,Q67,Q71,Q72,Q73,Q76,Q77,Q80,Q81,Q84,Q85,Q88,Q91,Q92,Q93,Q96,Q97,Q101,Q102,Q103,Q107,Q108,Q109,Q113,Q114,Q115,Q118,Q119,Q121,Q124,Q125,Q128,Q129,Q133,Q134,Q135,Q138,Q139,Q143,Q144,Q145,Q149,Q150,Q151,Q155,Q156,Q157,Q160,Q161,Q164,Q165,Q168,Q169,Q172,Q175,Q176,Q177,Q180,Q181,Q185,Q186,Q187,Q191,Q192,Q193,Q197,Q198,Q199,Q202,Q203,Q205,Q208,Q209,Q212,Q213,Q217,Q218,Q219,Q222,Q223,Q227,Q228,Q229,Q233,Q234,Q235,Q239,Q240,Q241,Q244,Q245,Q248,Q249,Q252,Q253,Q256,Q259,Q260,Q261,Q264,Q265,Q269,Q270,Q271,Q275,Q276,Q277,Q281,Q282,Q283,Q286,Q287,Q289,Q292,Q293,Q296,Q297,Q301,Q302,Q303,Q306,Q307,Q311,Q312,Q313,Q317,Q318,Q319,Q323,Q324,Q325,Q328,Q329,Q332,Q334,Q336,Q338,Q340,Q343,Q344,Q345,Q348,Q349,Q353,Q354,Q355,Q359,Q360,Q361,Q365,Q366,Q367,Q370,Q371,Q374,Q376,Q378,Q380,Q382,Q384,Q386,Q388,Q390,Q392,Q394,Q396,Q398,Q400,Q402,Q404,Q406,Q408,Q410,Q412,Q414,Q416,Q418,Q420,Q421,Q422,Q426,Q428,Q431,Q432,Q433,Q437,Q438,Q439,Q443,Q444,Q445,Q449,Q450,Q451,Q455,Q456,Q457,Q461,Q462,Q463,Q467,Q468,Q469,Q473,Q474,Q475,Q479,Q480,Q484,Q485,Q486,Q490,Q491,Q492,Q493,Q496,Q500,Q501,Q502,Q506,Q507,Q508,Q512,Q513,Q514,Q515,Q518,Q519,Q522,Q523,Q526,Q527,Q530,Q531,Q534,Q535,Q538,Q539,Q542,Q543,Q546,Q549,Q550,Q551,Q555,Q556,Q557,Q561,Q562,Q563,Q567,Q568,Q569,Q573,Q574,Q575,Q579,Q580,Q581,Q585,Q586,Q587,Q591,Q592,Q593,Q597,Q598,Q602,Q603,Q604,Q608,Q609,Q610,Q613,Q614,Q615,Q619,Q620,Q6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 | LogicQ:SOT-23-N | C8545
1K | R1,R3,R5,R7,R9,R10,R12,R14,R16,R18,R19,R21,R23,R25,R27,R28,R30,R32,R34,R36,R37,R39,R41,R43,R45,R46,R48,R50,R52,R54,R55,R57,R59,R61,R63,R64,R66,R68,R70,R72,R73,R75,R77,R79,R81,R92,R94,R96,R99,R103,R104,R106 | LogicQ:R_0603_1608Metric_NOLBL | C21190
20K | R2,R4,R6,R8,R11,R13,R15,R17,R20,R22,R24,R26,R29,R31,R33,R35,R38,R40,R42,R44,R47,R49,R51,R53,R56,R58,R60,R62,R65,R67,R69,R71,R74,R76,R78,R80,R91,R93,R102,R105,R107,R108 | Resistor_SMD:R_0603_1608Metric | C4184
10K | R82,R83,R84,R85,R86,R87,R88,R89,R90 | Resistor_SMD:R_0603_1608Metric | C25804
1M | R97 | Resistor_SMD:R_0603_1608Metric | C22935
L7805 | U1 | Package_TO_SOT_SMD:TO-252-2 | C58069
LM555xM | U3 | Package_SO:SOIC-8_3.9x4.9mm_P1.27mm | C7593

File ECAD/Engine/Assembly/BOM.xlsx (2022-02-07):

Comment | Designator | Footprint | LCSC
BSS84 | Q1,Q3,Q5,Q7,Q9,Q11,Q13,Q15,Q17,Q19,Q21,Q23,Q25,Q27,Q29,Q31,Q33,Q35,Q37,Q40,Q41,Q43,Q46,Q47,Q49,Q52,Q53,Q55,Q58,Q59,Q61,Q64,Q65,Q67,Q70,Q71,Q73,Q76,Q77,Q79,Q82,Q83,Q85,Q88,Q89,Q92,Q93,Q96,Q97,Q98,Q101,Q103,Q104,Q107,Q108,Q109,Q113,Q114,Q115,Q119,Q121,Q123,Q124,Q125,Q129,Q130,Q131,Q135,Q136,Q137,Q142,Q143,Q146,Q147,Q148,Q151,Q153,Q154,Q157,Q158,Q159,Q163,Q164,Q165,Q169,Q171,Q174,Q175,Q176,Q179,Q180,Q181,Q185,Q188,Q189,Q192,Q193,Q194,Q197,Q199,Q201,Q202,Q203,Q207,Q208,Q209,Q213,Q214,Q215,Q219,Q220,Q223,Q224,Q225,Q229,Q230,Q231,Q235,Q237,Q240,Q241,Q245,Q246,Q247,Q249,Q252,Q253,Q257,Q258,Q259,Q261,Q264,Q265,Q269,Q270,Q271,Q273,Q276,Q277,Q281,Q282,Q283,Q285,Q288,Q289,Q292,Q293,Q295,Q298,Q299,Q302,Q303,Q305,Q308,Q309,Q312,Q313,Q315,Q318,Q319,Q322,Q323,Q325,Q328,Q329,Q332,Q333,Q335,Q338,Q339,Q342,Q343,Q345,Q348,Q349,Q352,Q353,Q356,Q357,Q361,Q362,Q363,Q364,Q367,Q370,Q371,Q375,Q376,Q377,Q378,Q381,Q384,Q385,Q389,Q390,Q391,Q392,Q395,Q398,Q399,Q401,Q404,Q405,Q408,Q409,Q413,Q414,Q415,Q416,Q419,Q422,Q423,Q427,Q428,Q429,Q430,Q433,Q436,Q437,Q441,Q442,Q443,Q444,Q447,Q450,Q451,Q455,Q456,Q457,Q458,Q461,Q464,Q465,Q469,Q470,Q471,Q472,Q475,Q478,Q479,Q483,Q484,Q485,Q486,Q489,Q492,Q493,Q497,Q498,Q499,Q500,Q503,Q506,Q507,Q511,Q512,Q513,Q514,Q517,Q520,Q521,Q525,Q526,Q527,Q528,Q531,Q534,Q535,Q539,Q540,Q541,Q542,Q545,Q548,Q549,Q553,Q554,Q555,Q556,Q559,Q562,Q563,Q567,Q568,Q569,Q570,Q573,Q576,Q577,Q581,Q582,Q583,Q584,Q587,Q590,Q591,Q595,Q596,Q597,Q598,Q601,Q604,Q605,Q609,Q610,Q611,Q612,Q615,Q618,Q619,Q62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 | LogicQ:SOT-23-P | C114481
2N7002 | Q2,Q4,Q6,Q8,Q10,Q12,Q14,Q16,Q18,Q20,Q22,Q24,Q26,Q28,Q30,Q32,Q34,Q36,Q38,Q39,Q42,Q44,Q45,Q48,Q50,Q51,Q54,Q56,Q57,Q60,Q62,Q63,Q66,Q68,Q69,Q72,Q74,Q75,Q78,Q80,Q81,Q84,Q86,Q87,Q90,Q91,Q94,Q95,Q99,Q100,Q102,Q105,Q106,Q110,Q111,Q112,Q116,Q117,Q118,Q120,Q122,Q126,Q127,Q128,Q132,Q133,Q134,Q138,Q139,Q140,Q141,Q144,Q145,Q149,Q150,Q152,Q155,Q156,Q160,Q161,Q162,Q166,Q167,Q168,Q170,Q172,Q173,Q177,Q178,Q182,Q183,Q184,Q186,Q187,Q190,Q191,Q195,Q196,Q198,Q200,Q204,Q205,Q206,Q210,Q211,Q212,Q216,Q217,Q218,Q221,Q222,Q226,Q227,Q228,Q232,Q233,Q234,Q236,Q238,Q239,Q242,Q243,Q244,Q248,Q250,Q251,Q254,Q255,Q256,Q260,Q262,Q263,Q266,Q267,Q268,Q272,Q274,Q275,Q278,Q279,Q280,Q284,Q286,Q287,Q290,Q291,Q294,Q296,Q297,Q300,Q301,Q304,Q306,Q307,Q310,Q311,Q314,Q316,Q317,Q320,Q321,Q324,Q326,Q327,Q330,Q331,Q334,Q336,Q337,Q340,Q341,Q344,Q346,Q347,Q350,Q351,Q354,Q355,Q358,Q359,Q360,Q365,Q366,Q368,Q369,Q372,Q373,Q374,Q379,Q380,Q382,Q383,Q386,Q387,Q388,Q393,Q394,Q396,Q397,Q400,Q402,Q403,Q406,Q407,Q410,Q411,Q412,Q417,Q418,Q420,Q421,Q424,Q425,Q426,Q431,Q432,Q434,Q435,Q438,Q439,Q440,Q445,Q446,Q448,Q449,Q452,Q453,Q454,Q459,Q460,Q462,Q463,Q466,Q467,Q468,Q473,Q474,Q476,Q477,Q480,Q481,Q482,Q487,Q488,Q490,Q491,Q494,Q495,Q496,Q501,Q502,Q504,Q505,Q508,Q509,Q510,Q515,Q516,Q518,Q519,Q522,Q523,Q524,Q529,Q530,Q532,Q533,Q536,Q537,Q538,Q543,Q544,Q546,Q547,Q550,Q551,Q552,Q557,Q558,Q560,Q561,Q564,Q565,Q566,Q571,Q572,Q574,Q575,Q578,Q579,Q580,Q585,Q586,Q588,Q589,Q592,Q593,Q594,Q599,Q600,Q602,Q603,Q606,Q607,Q608,Q613,Q614,Q616,Q617,Q620,Q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 | LogicQ:SOT-23-N | C8545

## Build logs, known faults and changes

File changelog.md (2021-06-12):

# v1.0
    - Move to better switches
    - Implemented engine in transistors

# v0.2
    - Fixed Mem Cell
    - Fixed 'Draw' LED
    - Changed Capacitor
    - Fixed Button Order (AGAIN)

# v0.1
    - Fixed broken/shorting MUXes
    - Fixed Small silkscreen errors
    - Changed Board Mem Cells to not use MUXes

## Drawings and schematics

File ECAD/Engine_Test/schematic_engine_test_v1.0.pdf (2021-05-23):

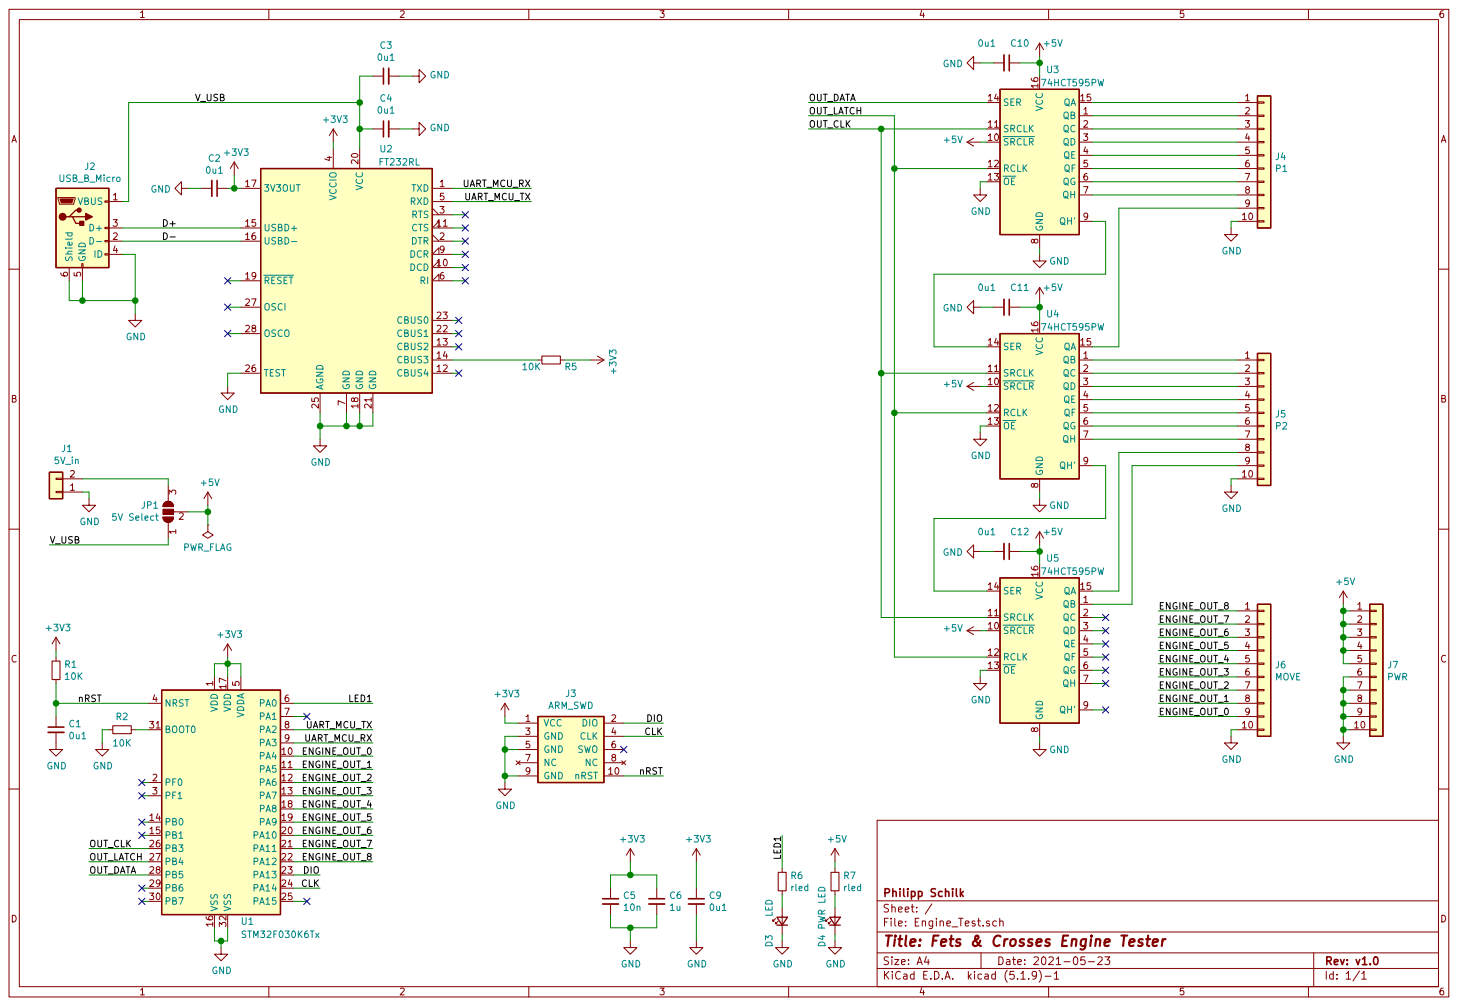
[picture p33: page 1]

1 PA4 10 PA5 11 PA6 12 PA7 13 PB0 14 PB1 15 VSS 16 VDD 17 PA8 18 PA9 19 PF0 2 PA10 20 PA11 21 PA12 22 PA13 23 PA14 24 PA15 25 PB3 26 PB4 27 PB5 28 PB6 29 PF1 3 PB7 30 BOOT0 31 VSS 32 NRST 4 VDDA

File: Engine_Test.sch Sheet: / Philipp Schilk

Id: 1/1 Title: Fets & Crosses Engine Tester

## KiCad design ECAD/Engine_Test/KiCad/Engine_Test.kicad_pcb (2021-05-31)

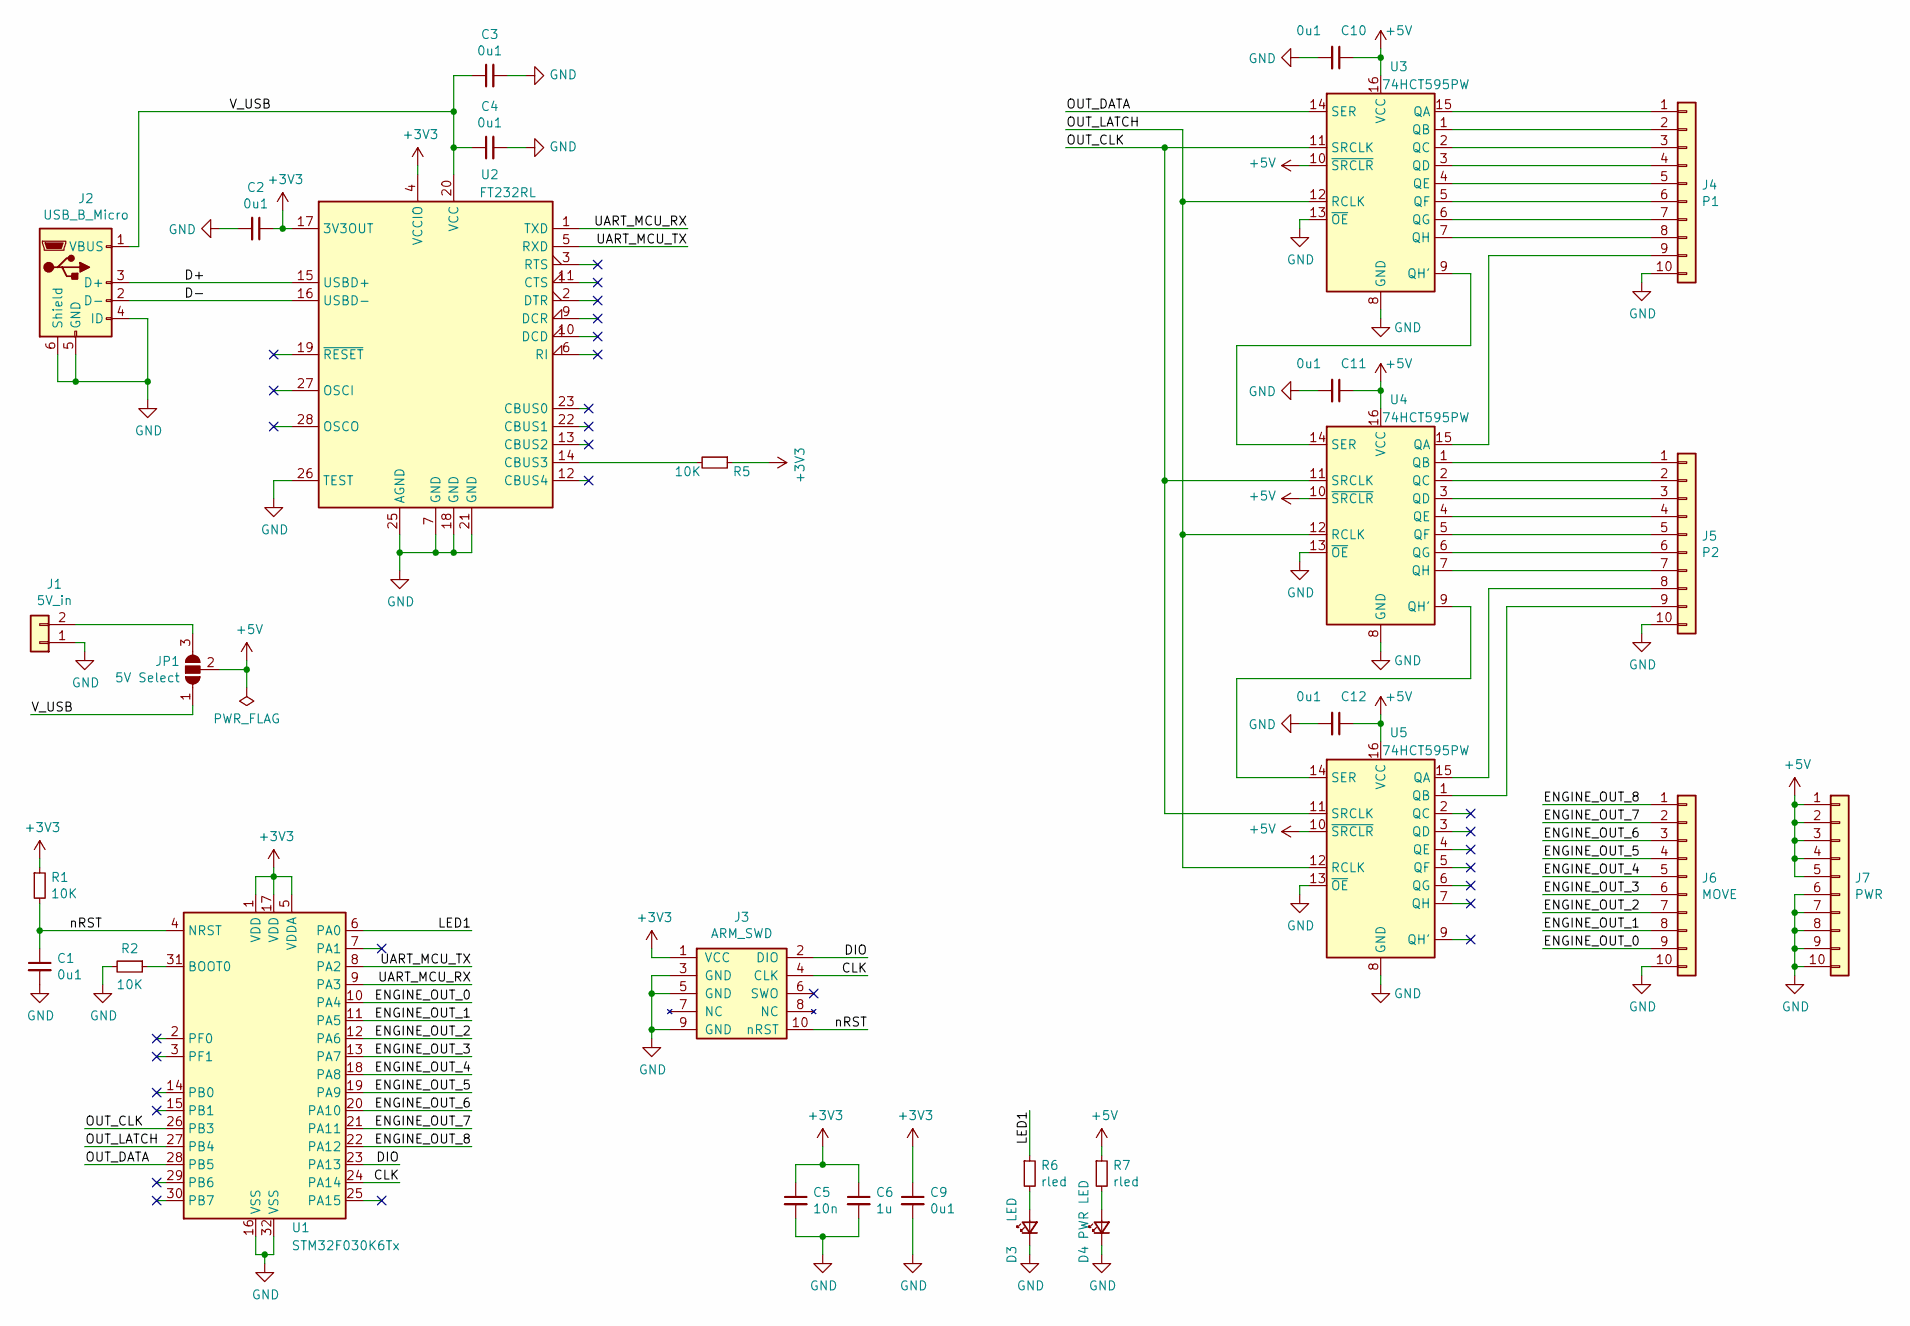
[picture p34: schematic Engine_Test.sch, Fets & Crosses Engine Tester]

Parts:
C1, C2, C3, C4, C9, C10, C11, C12: 0u1; C_0603_1608Metric
C5: 10n; C_0603_1608Metric
C6: 1u; C_0603_1608Metric
D3: LED; LED_0603_1608Metric
D4: PWR LED; LED_0603_1608Metric
J1: 5V_in; PinHeader_1x02_P2.54mm_Vertical
J2: USB_B_Micro; USB_Mini-B_Wuerth_65100516121_Horizontal
J3: ARM_SWD; PinHeader_2x05_P1.27mm_Vertical
J4: P1; PinSocket_1x10_P2.54mm_Horizontal
J5: P2; PinSocket_1x10_P2.54mm_Horizontal
J6: MOVE; PinSocket_1x10_P2.54mm_Horizontal
J7: PWR; PinSocket_1x10_P2.54mm_Horizontal
JP1: 5V Select; SolderJumper-3_P1.3mm_Open_RoundedPad1.0x1.5mm
R1, R2, R5: 10K; R_0603_1608Metric
R6, R7: rled; R_0603_1608Metric
U1: STM32F030K6Tx; LQFP-32_7x7mm_P0.8mm
U2: FT232RL; SSOP-28_5.3x10.2mm_P0.65mm
U3, U4, U5: 74HCT595PW; TSSOP-16_4.4x5mm_P0.65mm

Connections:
+3V3: C2.1, C5.1, C6.1, C9.1, J3.1 (VCC), R1.1, R5.1, U1.1 (VDD), U1.5 (VDDA), U1.17 (VDD), U2.4 (VCCIO), U2.17 (3V3OUT)
+5V: C10.1, C11.1, C12.1, J7.1, J7.2, J7.3, J7.4, J7.5, JP1.2 (C), R7.1, U3.10 (~SRCLR), U3.16 (VCC), U4.10 (~SRCLR), U4.16 (VCC), U5.10 (~SRCLR), U5.16 (VCC)
/CLK: J3.4 (CLK), U1.24 (PA14)
/D+: J2.3 (D+), U2.15 (USBD+)
/D-: J2.2 (D-), U2.16 (USBD-)
/DIO: J3.2 (DIO), U1.23 (PA13)
/ENGINE_OUT_0: J6.9, U1.10 (PA4)
/ENGINE_OUT_1: J6.8, U1.11 (PA5)
/ENGINE_OUT_2: J6.7, U1.12 (PA6)
/ENGINE_OUT_3: J6.6, U1.13 (PA7)
/ENGINE_OUT_4: J6.5, U1.18 (PA8)
/ENGINE_OUT_5: J6.4, U1.19 (PA9)
/ENGINE_OUT_6: J6.3, U1.20 (PA10)
/ENGINE_OUT_7: J6.2, U1.21 (PA11)
/ENGINE_OUT_8: J6.1, U1.22 (PA12)
/LED1: R6.1, U1.6 (PA0)
/OUT_CLK: U1.26 (PB3), U3.11 (SRCLK), U4.11 (SRCLK), U5.11 (SRCLK)
/OUT_DATA: U1.28 (PB5), U3.14 (SER)
/OUT_LATCH: U1.27 (PB4), U3.12 (RCLK), U4.12 (RCLK), U5.12 (RCLK)
/UART_MCU_RX: U1.9 (PA3), U2.1 (TXD)
/UART_MCU_TX: U1.8 (PA2), U2.5 (RXD)
/V_USB: C3.1, C4.1, J2.1 (VBUS), JP1.1 (A), U2.20 (VCC)
/nRST: C1.1, J3.10 (nRST), R1.2, U1.4 (NRST)
GND: C1.2, C2.2, C3.2, C4.2, C5.2, C6.2, C9.2, C10.2, C11.2, C12.2, D3.1 (K), D4.1 (K), J1.1, J2.4 (ID), J2.5 (GND), J2.6 (Shield), J3.3 (GND), J3.5 (GND), J3.9 (GND), J4.10, J5.10, J6.10, J7.6, J7.7, J7.8, J7.9, J7.10, R2.2, U1.16 (VSS), U1.32 (VSS), U2.7 (GND), U2.18 (GND), U2.21 (GND), U2.25 (AGND), U2.26 (TEST), U3.8 (GND), U3.13 (~OE), U4.8 (GND), U4.13 (~OE), U5.8 (GND), U5.13 (~OE)
unnamed: D3.2 (A), R6.2
unnamed: D4.2 (A), R7.2
unnamed: J1.2, JP1.3 (B)
unnamed: J4.1, U3.15 (QA)
unnamed: J4.2, U3.1 (QB)
unnamed: J4.3, U3.2 (QC)
unnamed: J4.4, U3.3 (QD)
unnamed: J4.5, U3.4 (QE)
unnamed: J4.6, U3.5 (QF)
unnamed: J4.7, U3.6 (QG)
unnamed: J4.8, U3.7 (QH)
unnamed: J4.9, U4.15 (QA)
unnamed: J5.1, U4.1 (QB)
unnamed: J5.2, U4.2 (QC)
unnamed: J5.3, U4.3 (QD)
unnamed: J5.4, U4.4 (QE)
unnamed: J5.5, U4.5 (QF)
unnamed: J5.6, U4.6 (QG)
unnamed: J5.7, U4.7 (QH)
unnamed: J5.8, U5.15 (QA)
unnamed: J5.9, U5.1 (QB)
unnamed: R2.1, U1.31 (BOOT0)
unnamed: R5.2, U2.14 (CBUS3)
unnamed: U3.9 (QH'), U4.14 (SER)
unnamed: U4.9 (QH'), U5.14 (SER)

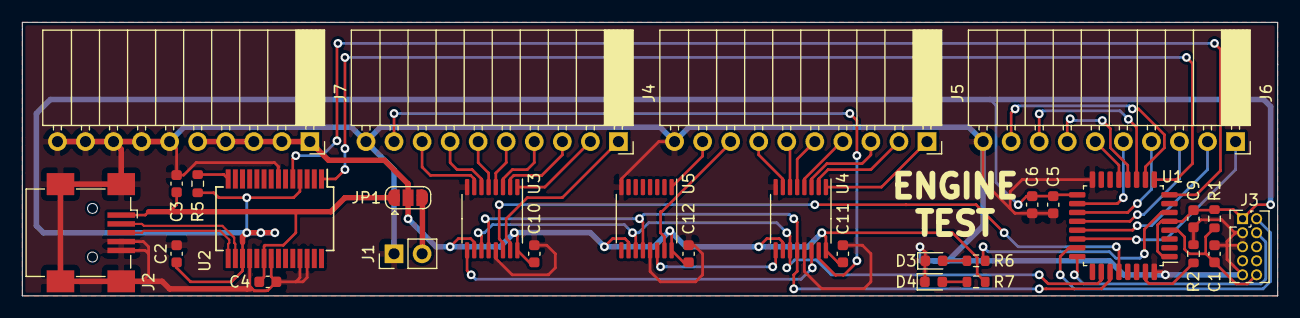
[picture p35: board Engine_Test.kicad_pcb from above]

Board: 2 copper layers, 113.7 x 24.8 mm, 30 parts (0 on the bottom side), 49 nets.

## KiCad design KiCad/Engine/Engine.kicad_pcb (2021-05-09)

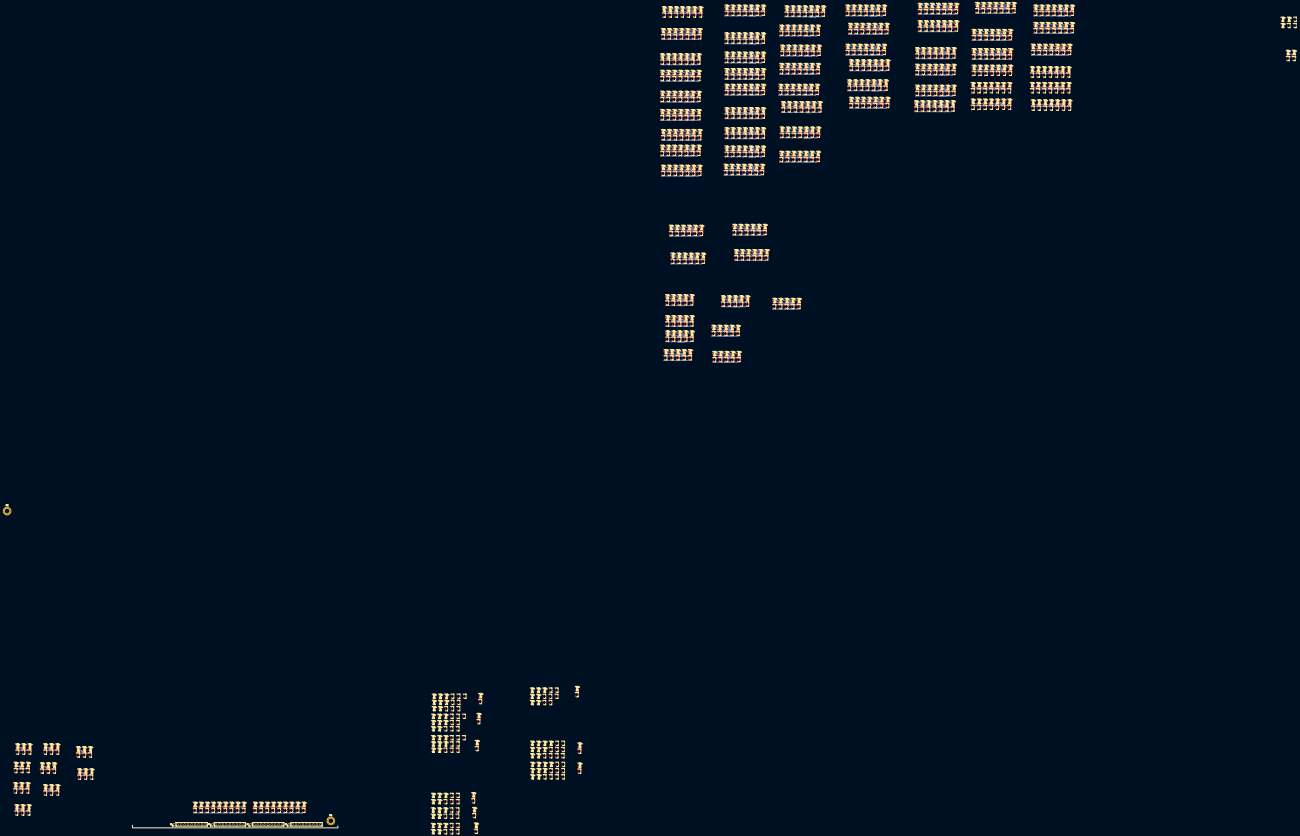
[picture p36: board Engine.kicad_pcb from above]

Board: 2 copper layers, 1080 parts (0 on the bottom side), 567 nets.

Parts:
H1, H2: MountingHole; MountingHole_3.2mm_M3_Pad_Via
J1: Power; PinHeader_1x10_P2.54mm_Vertical
J3: P1; PinHeader_1x10_P2.54mm_Vertical
J4: P2; PinHeader_1x10_P2.54mm_Vertical
J5: Move; PinHeader_1x10_P2.54mm_Vertical
Q1, Q3, Q5, Q7, Q9, Q11, Q13, Q15, Q17, Q19, Q21, Q23, Q25, Q27, Q29, Q31, Q33, Q35, Q37, Q40, Q41, Q43, Q46, Q47, Q49, Q52, Q53, Q55, Q58, Q59, Q61, Q64, Q65, Q67, Q70, Q71, Q73, Q76, Q77, Q79, Q82, Q83, Q85, Q88, Q89, Q92, Q93, Q96, Q97, Q98, Q101, Q103, Q104, Q107, Q108, Q109, Q113, Q114, Q115, Q119, Q121, Q123, Q124, Q125, Q129, Q130, Q131, Q135, Q136, Q137, Q142, Q143, Q146, Q147, Q148, Q151, Q153, Q154, Q157, Q158, Q159, Q163, Q164, Q165, Q169, Q171, Q174, Q175, Q176, Q179, Q180, Q181, Q185, Q188, Q189, Q192, Q193, Q194, Q197, Q199, Q201, Q202, Q203, Q207, Q208, Q209, Q213, Q214, Q215, Q219, Q220, Q223, Q224, Q225, Q229, Q230, Q231, Q235, Q237, Q240, Q241, Q245, Q246, Q247, Q249, Q252, Q253, Q257, Q258, Q259, Q261, Q264, Q265, Q269, Q270, Q271, Q273, Q276, Q277, Q281, Q282, Q283, Q285, Q288, Q289, Q292, Q293, Q295, Q298, Q299, Q302, Q303, Q305, Q308, Q309, Q312, Q313, Q315, Q318, Q319, Q322, Q323, Q325, Q328, Q329, Q332, Q333, Q335, Q338, Q339, Q342, Q343, Q345, Q348, Q349, Q352, Q353, Q356, Q357, Q361, Q362, Q363, Q364, Q367, Q370, Q371, Q375, Q376, Q377, Q378, Q381, Q384, Q385, Q389, Q390, Q391, Q392, Q395, Q398, Q399, Q401, Q404, Q405, Q408, Q409, Q413, Q414, Q415, Q416, Q419, Q422, Q423, Q427, Q428, Q429, Q430, Q433, Q436, Q437, Q441, Q442, Q443, Q444, Q447, Q450, Q451, Q455, Q456, Q457, Q458, Q461, Q464, Q465, Q469, Q470, Q471, Q472, Q475, Q478, Q479, Q483, Q484, Q485, Q486, Q489, Q492, Q493, Q497, Q498, Q499, Q500, Q503, Q506, Q507, Q511, Q512, Q513, Q514, Q517, Q520, Q521, Q525, Q526, Q527, Q528, Q531, Q534, Q535, Q539, Q540, Q541, Q542, Q545, Q548, Q549, Q553, Q554, Q555, Q556, Q559, Q562, Q563, Q567, Q568, Q569, Q570, Q573, Q576, Q577, Q581, Q582, Q583, Q584, Q587, Q590, Q591, Q595, Q596, Q597, Q598, Q601, Q604, Q605, Q609, Q610, Q611, Q612, Q615, Q618, Q619, Q623, Q624, Q625, Q626, Q629, Q632, Q633, Q637, Q638, Q639, Q640, Q643, Q646, Q647, Q651, Q652, Q653, Q654, Q657, Q660, Q661, Q665, Q666, Q667, Q668, Q671, Q674, Q675, Q679, Q680, Q681, Q682, Q685, Q688, Q689, Q693, Q694, Q695, Q696, Q699, Q702, Q703, Q707, Q708, Q709, Q710, Q713, Q716, Q717, Q721, Q722, Q723, Q724, Q727, Q730, Q731, Q735, Q736, Q737, Q738, Q741, Q744, Q745, Q749, Q750, Q751, Q752, Q755, Q758, Q759, Q763, Q764, Q765, Q766, Q769, Q772, Q773, Q777, Q778, Q779, Q780, Q783, Q786, Q787, Q791, Q792, Q793, Q794, Q797, Q800, Q801, Q805, Q806, Q807, Q808, Q811, Q814, Q815, Q819, Q820, Q821, Q822, Q825, Q828, Q829, Q833, Q834, Q835, Q836, Q839, Q842, Q843, Q847, Q848, Q849, Q850, Q853, Q856, Q857, Q861, Q862, Q863, Q864, Q867, Q870, Q871, Q875, Q876, Q877, Q878, Q881, Q884, Q885, Q889, Q890, Q891, Q892, Q895, Q898, Q899, Q903, Q904, Q905, Q906, Q909, Q912, Q913, Q917, Q918, Q919, Q920, Q923, Q926, Q927, Q931, Q932, Q933, Q934, Q937, Q940, Q941, Q945, Q946, Q947, Q948, Q951, Q954, Q955, Q959, Q960, Q961, Q962, Q965, Q968, Q969, Q973, Q974, Q975, Q979, Q980, Q981, Q982, Q985, Q988, Q989, Q993, Q994, Q995, Q996, Q999, Q1002, Q1003, Q1007, Q1008, Q1009, Q1010, Q1013, Q1016, Q1017, Q1021, Q1022, Q1023, Q1024, Q1027, Q1030, Q1031, Q1035, Q1036, Q1037, Q1038, Q1041, Q1044, Q1045, Q1049, Q1050, Q1051, Q1052, Q1055, Q1058, Q1059, Q1063, Q1064, Q1065, Q1066, Q1069, Q1072, Q1073: BSS84; SOT-23-P
Q2, Q4, Q6, Q8, Q10, Q12, Q14, Q16, Q18, Q20, Q22, Q24, Q26, Q28, Q30, Q32, Q34, Q36, Q38, Q39, Q42, Q44, Q45, Q48, Q50, Q51, Q54, Q56, Q57, Q60, Q62, Q63, Q66, Q68, Q69, Q72, Q74, Q75, Q78, Q80, Q81, Q84, Q86, Q87, Q90, Q91, Q94, Q95, Q99, Q100, Q102, Q105, Q106, Q110, Q111, Q112, Q116, Q117, Q118, Q120, Q122, Q126, Q127, Q128, Q132, Q133, Q134, Q138, Q139, Q140, Q141, Q144, Q145, Q149, Q150, Q152, Q155, Q156, Q160, Q161, Q162, Q166, Q167, Q168, Q170, Q172, Q173, Q177, Q178, Q182, Q183, Q184, Q186, Q187, Q190, Q191, Q195, Q196, Q198, Q200, Q204, Q205, Q206, Q210, Q211, Q212, Q216, Q217, Q218, Q221, Q222, Q226, Q227, Q228, Q232, Q233, Q234, Q236, Q238, Q239, Q242, Q243, Q244, Q248, Q250, Q251, Q254, Q255, Q256, Q260, Q262, Q263, Q266, Q267, Q268, Q272, Q274, Q275, Q278, Q279, Q280, Q284, Q286, Q287, Q290, Q291, Q294, Q296, Q297, Q300, Q301, Q304, Q306, Q307, Q310, Q311, Q314, Q316, Q317, Q320, Q321, Q324, Q326, Q327, Q330, Q331, Q334, Q336, Q337, Q340, Q341, Q344, Q346, Q347, Q350, Q351, Q354, Q355, Q358, Q359, Q360, Q365, Q366, Q368, Q369, Q372, Q373, Q374, Q379, Q380, Q382, Q383, Q386, Q387, Q388, Q393, Q394, Q396, Q397, Q400, Q402, Q403, Q406, Q407, Q410, Q411, Q412, Q417, Q418, Q420, Q421, Q424, Q425, Q426, Q431, Q432, Q434, Q435, Q438, Q439, Q440, Q445, Q446, Q448, Q449, Q452, Q453, Q454, Q459, Q460, Q462, Q463, Q466, Q467, Q468, Q473, Q474, Q476, Q477, Q480, Q481, Q482, Q487, Q488, Q490, Q491, Q494, Q495, Q496, Q501, Q502, Q504, Q505, Q508, Q509, Q510, Q515, Q516, Q518, Q519, Q522, Q523, Q524, Q529, Q530, Q532, Q533, Q536, Q537, Q538, Q543, Q544, Q546, Q547, Q550, Q551, Q552, Q557, Q558, Q560, Q561, Q564, Q565, Q566, Q571, Q572, Q574, Q575, Q578, Q579, Q580, Q585, Q586, Q588, Q589, Q592, Q593, Q594, Q599, Q600, Q602, Q603, Q606, Q607, Q608, Q613, Q614, Q616, Q617, Q620, Q621, Q622, Q627, Q628, Q630, Q631, Q634, Q635, Q636, Q641, Q642, Q644, Q645, Q648, Q649, Q650, Q655, Q656, Q658, Q659, Q662, Q663, Q664, Q669, Q670, Q672, Q673, Q676, Q677, Q678, Q683, Q684, Q686, Q687, Q690, Q691, Q692, Q697, Q698, Q700, Q701, Q704, Q705, Q706, Q711, Q712, Q714, Q715, Q718, Q719, Q720, Q725, Q726, Q728, Q729, Q732, Q733, Q734, Q739, Q740, Q742, Q743, Q746, Q747, Q748, Q753, Q754, Q756, Q757, Q760, Q761, Q762, Q767, Q768, Q770, Q771, Q774, Q775, Q776, Q781, Q782, Q784, Q785, Q788, Q789, Q790, Q795, Q796, Q798, Q799, Q802, Q803, Q804, Q809, Q810, Q812, Q813, Q816, Q817, Q818, Q823, Q824, Q826, Q827, Q830, Q831, Q832, Q837, Q838, Q840, Q841, Q844, Q845, Q846, Q851, Q852, Q854, Q855, Q858, Q859, Q860, Q865, Q866, Q868, Q869, Q872, Q873, Q874, Q879, Q880, Q882, Q883, Q886, Q887, Q888, Q893, Q894, Q896, Q897, Q900, Q901, Q902, Q907, Q908, Q910, Q911, Q914, Q915, Q916, Q921, Q922, Q924, Q925, Q928, Q929, Q930, Q935, Q936, Q938, Q939, Q942, Q943, Q944, Q949, Q950, Q952, Q953, Q956, Q957, Q958, Q963, Q964, Q966, Q967, Q970, Q971, Q972, Q976, Q977, Q978, Q983, Q984, Q986, Q987, Q990, Q991, Q992, Q997, Q998, Q1000, Q1001, Q1004, Q1005, Q1006, Q1011, Q1012, Q1014, Q1015, Q1018, Q1019, Q1020, Q1025, Q1026, Q1028, Q1029, Q1032, Q1033, Q1034, Q1039, Q1040, Q1042, Q1043, Q1046, Q1047, Q1048, Q1053, Q1054, Q1056, Q1057, Q1060, Q1061, Q1062, Q1067, Q1068, Q1070, Q1071, Q1074: 2N7002; SOT-23-N

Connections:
+5V: J1.6, J1.7, J1.8, J1.9, J1.10, Q1.2, Q3.2, Q5.2, Q7.2, Q9.2, Q11.2, Q13.2, Q15.2, Q17.2, Q19.2, Q21.2, Q23.2, Q25.2, Q27.2, Q29.2, Q31.2, Q33.2, Q35.2, Q37.2, Q40.2, Q43.2, Q46.2, Q49.2, Q52.2, Q55.2, Q58.2, Q61.2, Q64.2, Q67.2, Q70.2, Q73.2, Q76.2, Q79.2, Q82.2, Q85.2, Q88.2, Q92.2, Q101.2, Q103.2, Q119.2, Q121.2, Q123.2, Q142.2, Q151.2, Q153.2, Q169.2, Q171.2, Q185.2, Q188.2, Q197.2, Q199.2, Q201.2, Q219.2, Q235.2, Q237.2, Q240.2, Q245.2, Q249.2, Q252.2, Q257.2, Q261.2, Q264.2, Q269.2, Q273.2, Q276.2, Q281.2, Q285.2, Q288.2, Q292.2, Q295.2, Q298.2, Q302.2, Q305.2, Q308.2, Q312.2, Q315.2, Q318.2, Q322.2, Q325.2, Q328.2, Q332.2, Q335.2, Q338.2, Q342.2, Q345.2, Q348.2, Q352.2, Q356.2, Q361.2, Q367.2, Q370.2, Q375.2, Q381.2, Q384.2, Q389.2, Q395.2, Q398.2, Q401.2, Q404.2, Q408.2, Q413.2, Q419.2, Q422.2, Q427.2, Q433.2, Q436.2, Q441.2, Q447.2, Q450.2, Q455.2, Q461.2, Q464.2, Q469.2, Q475.2, Q478.2, Q483.2, Q489.2, Q492.2, Q497.2, Q503.2, Q506.2, Q511.2, Q517.2, Q520.2, Q525.2, Q531.2, Q534.2, Q539.2, Q545.2, Q548.2, Q553.2, Q559.2, Q562.2, Q567.2, Q573.2, Q576.2, Q581.2, Q587.2, Q590.2, Q595.2, Q601.2, Q604.2, Q609.2, Q615.2, Q618.2, Q623.2, Q629.2, Q632.2, Q637.2, Q643.2, Q646.2, Q651.2, Q657.2, Q660.2, Q665.2, Q671.2, Q674.2, Q679.2, Q685.2, Q688.2, Q693.2, Q699.2, Q702.2, Q707.2, Q713.2, Q716.2, Q721.2, Q727.2, Q730.2, Q735.2, Q741.2, Q744.2, Q749.2, Q755.2, Q758.2, Q763.2, Q769.2, Q772.2, Q777.2, Q783.2, Q786.2, Q791.2, Q797.2, Q800.2, Q805.2, Q811.2, Q814.2, Q819.2, Q825.2, Q828.2, Q833.2, Q839.2, Q842.2, Q847.2, Q853.2, Q856.2, Q861.2, Q867.2, Q870.2, Q875.2, Q881.2, Q884.2, Q889.2, Q895.2, Q898.2, Q903.2, Q909.2, Q912.2, Q917.2, Q923.2, Q926.2, Q931.2, Q937.2, Q940.2, Q945.2, Q951.2, Q954.2, Q959.2, Q965.2, Q968.2, Q973.2, Q979.2, Q985.2, Q988.2, Q993.2, Q999.2, Q1002.2, Q1007.2, Q1013.2, Q1016.2, Q1021.2, Q1027.2, Q1030.2, Q1035.2, Q1041.2, Q1044.2, Q1049.2, Q1055.2, Q1058.2, Q1063.2, Q1069.2, Q1072.2
/Board_P1_0: J3.10, Q1.1, Q2.1, Q39.1, Q40.1
/Board_P1_1: J3.9, Q3.1, Q4.1, Q45.1, Q46.1
/Board_P1_2: J3.8, Q5.1, Q6.1, Q51.1, Q52.1
/Board_P1_3: J3.7, Q7.1, Q8.1, Q57.1, Q58.1
/Board_P1_4: J3.6, Q9.1, Q10.1, Q63.1, Q64.1
/Board_P1_5: J3.5, Q11.1, Q12.1, Q69.1, Q70.1
/Board_P1_6: J3.4, Q13.1, Q14.1, Q75.1, Q76.1
/Board_P1_7: J3.3, Q15.1, Q16.1, Q81.1, Q82.1
/Board_P1_8: J3.2, Q17.1, Q18.1, Q87.1, Q88.1
/Board_P2_0: J4.10, Q19.1, Q20.1, Q41.1, Q42.1
/Board_P2_1: J4.9, Q21.1, Q22.1, Q47.1, Q48.1
/Board_P2_2: J4.8, Q23.1, Q24.1, Q53.1, Q54.1
/Board_P2_3: J4.7, Q25.1, Q26.1, Q59.1, Q60.1
/Board_P2_4: J4.6, Q27.1, Q28.1, Q65.1, Q66.1
/Board_P2_5: J4.5, Q29.1, Q30.1, Q71.1, Q72.1
/Board_P2_6: J4.4, Q31.1, Q32.1, Q77.1, Q78.1
/Board_P2_7: J4.3, Q33.1, Q34.1, Q83.1, Q84.1
/Board_P2_8: J4.2, Q35.1, Q36.1, Q89.1, Q90.1
/Computer0: J5.2, Q235.3, Q236.3
/Computer1: J5.3, Q197.3, Q198.3
/Computer2: J5.4, Q169.3, Q170.3
/Computer3: J5.5, Q151.3, Q152.3
/Computer4: J5.6, Q121.3, Q122.3
/Computer5: J5.7, Q101.3, Q102.3
/Computer6: J5.8, Q119.3, Q120.3
/Computer7: J5.9, Q185.3, Q186.3
/Computer8: J5.10, Q199.3, Q200.3
/M0_A: Q231.1, Q234.1, Q962.1, Q964.1, Q969.1, Q970.1, Q971.3, Q972.3, Q975.3, Q976.3
/M0_B: Q228.1, Q230.1, Q831.3, Q832.3, Q836.3, Q837.3, Q838.3, Q841.1, Q842.1
/M0_C: Q222.1, Q229.1, Q747.3, Q748.3, Q752.3, Q753.3, Q754.3, Q757.1, Q758.1
/M0_E: Q225.1, Q233.1, Q621.3, Q622.3, Q626.3, Q627.3, Q628.3, Q631.1, Q632.1
/M0_F: Q224.1, Q227.1, Q607.3, Q608.3, Q612.3, Q613.3, Q614.3, Q617.1, Q618.1
/M0_G: Q221.1, Q223.1, Q411.3, Q412.3, Q416.3, Q417.3, Q418.3, Q421.1, Q422.1
/M0_K: Q220.1, Q232.1, Q251.1, Q252.1, Q255.3, Q256.3, Q259.3, Q260.3
/M0_L: Q219.1, Q226.1, Q287.1, Q288.1, Q291.3, Q293.3, Q294.3
/M1_A: Q194.1, Q196.1, Q957.3, Q958.3, Q962.3, Q963.3, Q964.3, Q967.1, Q968.1
/M1_B: Q191.1, Q193.1, Q873.3, Q874.3, Q878.3, Q879.3, Q880.3, Q883.1, Q884.1
/M1_E: Q187.1, Q192.1, Q635.3, Q636.3, Q640.3, Q641.3, Q642.3, Q645.1, Q646.1
/M1_F: Q189.1, Q195.1, Q579.3, Q580.3, Q584.3, Q585.3, Q586.3, Q589.1, Q590.1
/M1_M: Q188.1, Q190.1, Q327.1, Q328.1, Q331.3, Q333.3, Q334.3
/M2_A: Q165.1, Q168.1, Q977.3, Q978.3, Q982.3, Q983.3, Q984.3, Q987.1, Q988.1
/M2_B: Q162.1, Q164.1, Q915.3, Q916.3, Q920.3, Q921.3, Q922.3, Q925.1, Q926.1
/M2_D: Q156.1, Q163.1, Q789.3, Q790.3, Q794.3, Q795.3, Q796.3, Q799.1, Q800.1
/M2_E: Q159.1, Q167.1, Q649.3, Q650.3, Q654.3, Q655.3, Q656.3, Q659.1, Q660.1
/M2_F: Q158.1, Q161.1, Q593.3, Q594.3, Q598.3, Q599.3, Q600.3, Q603.1, Q604.1
/M2_H: Q155.1, Q157.1, Q453.3, Q454.3, Q458.3, Q459.3, Q460.3, Q463.1, Q464.1
/M2_K: Q154.1, Q166.1, Q275.1, Q276.1, Q279.3, Q280.3, Q283.3, Q284.3
/M2_L: Q153.1, Q160.1, Q297.1, Q298.1, Q301.3, Q303.3, Q304.3
/M3_A: Q148.1, Q150.1, Q991.3, Q992.3, Q996.3, Q997.3, Q998.3, Q1001.1, Q1002.1
/M3_B: Q145.1, Q147.1, Q845.3, Q846.3, Q850.3, Q851.3, Q852.3, Q855.1, Q856.1
/M3_E: Q141.1, Q146.1, Q663.3, Q664.3, Q668.3, Q669.3, Q670.3, Q673.1, Q674.1
/M3_F: Q143.1, Q149.1, Q495.3, Q496.3, Q500.3, Q501.3, Q502.3, Q505.1, Q506.1
/M3_M: Q142.1, Q144.1, Q347.1, Q348.1, Q351.3, Q353.3, Q354.3
/M4_A: Q137.1, Q140.1, Q1005.3, Q1006.3, Q1010.3, Q1011.3, Q1012.3, Q1015.1, Q1016.1
/M4_B: Q134.1, Q136.1, Q887.3, Q888.3, Q892.3, Q893.3, Q894.3, Q897.1, Q898.1
/M4_C: Q128.1, Q135.1, Q761.3, Q762.3, Q766.3, Q767.3, Q768.3, Q771.1, Q772.1
/M4_D: Q131.1, Q139.1, Q803.3, Q804.3, Q808.3, Q809.3, Q810.3, Q813.1, Q814.1
/M4_E: Q130.1, Q133.1, Q677.3, Q678.3, Q682.3, Q683.3, Q684.3, Q687.1, Q688.1
/M4_F: Q127.1, Q129.1, Q523.3, Q524.3, Q528.3, Q529.3, Q530.3, Q533.1, Q534.1
/M4_G: Q125.1, Q138.1, Q425.3, Q426.3, Q430.3, Q431.3, Q432.3, Q435.1, Q436.1
/M4_H: Q124.1, Q132.1, Q467.3, Q468.3, Q472.3, Q473.3, Q474.3, Q477.1, Q478.1
/M4_I: Q123.1, Q126.1, Q403.1, Q404.1, Q407.3, Q409.3, Q410.3
/M5_A: Q98.1, Q100.1, Q1019.3, Q1020.3, Q1024.3, Q1025.3, Q1026.3, Q1029.1, Q1030.1
/M5_B: Q95.1, Q97.1, Q929.3, Q930.3, Q934.3, Q935.3, Q936.3, Q939.1, Q940.1
/M5_E: Q91.1, Q96.1, Q691.3, Q692.3, Q696.3, Q697.3, Q698.3, Q701.1, Q702.1
/M5_F: Q93.1, Q99.1, Q551.3, Q552.3, Q556.3, Q557.3, Q558.3, Q561.1, Q562.1
/M5_M: Q92.1, Q94.1, Q337.1, Q338.1, Q341.3, Q343.3, Q344.3
/M6_A: Q115.1, Q118.1, Q1033.3, Q1034.3, Q1038.3, Q1039.3, Q1040.3, Q1043.1, Q1044.1
/M6_B: Q112.1, Q114.1, Q859.3, Q860.3, Q864.3, Q865.3, Q866.3, Q869.1, Q870.1
/M6_D: Q106.1, Q113.1, Q817.3, Q818.3, Q822.3, Q823.3, Q824.3, Q827.1, Q828.1
/M6_E: Q109.1, Q117.1, Q705.3, Q706.3, Q710.3, Q711.3, Q712.3, Q715.1, Q716.1
/M6_F: Q108.1, Q111.1, Q509.3, Q510.3, Q514.3, Q515.3, Q516.3, Q519.1, Q520.1
/M6_H: Q105.1, Q107.1, Q481.3, Q482.3, Q486.3, Q487.3, Q488.3, Q491.1, Q492.1
/M6_K: Q104.1, Q116.1, Q239.1, Q240.1, Q243.3, Q244.3, Q247.3, Q248.3
/M6_L: Q103.1, Q110.1, Q307.1, Q308.1, Q311.3, Q313.3, Q314.3
/M7_A: Q181.1, Q184.1, Q1047.3, Q1048.3, Q1052.3, Q1053.3, Q1054.3, Q1057.1, Q1058.1
/M7_B: Q178.1, Q180.1, Q901.3, Q902.3, Q906.3, Q907.3, Q908.3, Q911.1, Q912.1
/M7_E: Q173.1, Q179.1, Q719.3, Q720.3, Q724.3, Q725.3, Q726.3, Q729.1, Q730.1
/M7_F: Q176.1, Q183.1, Q537.3, Q538.3, Q542.3, Q543.3, Q544.3, Q547.1, Q548.1
/M7_I: Q175.1, Q177.1, Q359.3, Q360.3, Q364.3, Q365.3, Q366.3, Q369.1, Q370.1
/M7_J: Q172.1, Q174.1, Q373.3, Q374.3, Q378.3, Q379.3, Q380.3, Q383.1, Q384.1
/M7_M: Q171.1, Q182.1, Q355.3, Q357.3, Q358.3
/M8_A: Q215.1, Q218.1, Q1061.3, Q1062.3, Q1066.3, Q1067.3, Q1068.3, Q1071.1, Q1072.1
/M8_B: Q212.1, Q214.1, Q943.3, Q944.3, Q948.3, Q949.3, Q950.3, Q953.1, Q954.1
/M8_C: Q206.1, Q213.1, Q775.3, Q776.3, Q780.3, Q781.3, Q782.3, Q785.1, Q786.1
/M8_E: Q209.1, Q217.1, Q733.3, Q734.3, Q738.3, Q739.3, Q740.3, Q743.1, Q744.1
/M8_F: Q208.1, Q211.1, Q565.3, Q566.3, Q570.3, Q571.3, Q572.3, Q575.1, Q576.1
/M8_G: Q205.1, Q207.1, Q439.3, Q440.3, Q444.3, Q445.3, Q446.3, Q449.1, Q450.1
/M8_I: Q203.1, Q216.1, Q387.3, Q388.3, Q392.3, Q393.3, Q394.3, Q397.1, Q398.1
/M8_K: Q202.1, Q210.1, Q263.1, Q264.1, Q267.3, Q268.3, Q271.3, Q272.3
/M8_L: Q201.1, Q204.1, Q317.1, Q318.1, Q321.3, Q323.3, Q324.3
/Sheet60D62401/sheet60D63D17/A: Q221.3, Q222.3, Q226.3, Q227.3, Q228.3, Q231.3, Q232.3, Q233.3, Q234.3, Q235.1, Q236.1
/Sheet6047D39E/OUT0: Q1.3, Q2.3, Q267.1, Q269.1, Q359.1, Q361.1, Q425.1, Q427.1, Q439.1, Q441.1, Q495.1, Q497.1, Q509.1, Q511.1, Q635.1, Q637.1, Q649.1, Q651.1
/Sheet6047D39E/OUT1: Q3.3, Q4.3, Q523.1, Q525.1, Q537.1, Q539.1, Q621.1, Q623.1, Q650.1, Q652.1
/Sheet6047D39E/OUT2: Q5.3, Q6.3, Q243.1, Q245.1, Q373.1, Q375.1, Q467.1, Q469.1, Q481.1, Q483.1, Q551.1, Q553.1, Q565.1, Q567.1, Q622.1, Q624.1, Q636.1, Q638.1
/Sheet6047D39E/OUT3: Q7.3, Q8.3, Q510.1, Q512.1, Q607.1, Q609.1, Q677.1, Q679.1, Q691.1, Q693.1
/Sheet6047D39E/OUT4: Q9.3, Q10.3, Q411.1, Q413.1, Q440.1, Q442.1, Q453.1, Q455.1, Q482.1, Q484.1, Q538.1, Q540.1, Q579.1, Q581.1, Q663.1, Q665.1, Q692.1, Q694.1
/Sheet6047D39E/OUT5: Q11.3, Q12.3, Q387.1, Q389.1, Q566.1, Q568.1, Q593.1, Q595.1, Q664.1, Q666.1, Q678.1, Q680.1
/Sheet6047D39E/OUT6: Q13.3, Q14.3, Q279.1, Q281.1, Q374.1, Q376.1, Q454.1, Q456.1, Q468.1, Q470.1, Q496.1, Q498.1, Q608.1, Q610.1, Q719.1, Q721.1, Q733.1, Q735.1
/Sheet6047D39E/OUT7: Q15.3, Q16.3, Q388.1, Q390.1, Q524.1, Q526.1, Q580.1, Q582.1, Q705.1, Q707.1, Q734.1, Q736.1
/Sheet6047D39E/OUT8: Q17.3, Q18.3, Q255.1, Q257.1, Q360.1, Q362.1, Q412.1, Q414.1, Q426.1, Q428.1, Q552.1, Q554.1, Q594.1, Q596.1, Q706.1, Q708.1, Q720.1, Q722.1
/Sheet6049469B/Q0: Q37.3, Q38.3, Q256.1, Q258.1, Q291.1, Q292.1, Q415.1, Q417.1, Q611.1, Q613.1, Q625.1, Q627.1, Q751.1, Q753.1, Q835.1, Q837.1, Q975.1, Q976.1
/Sheet6049469B/Q1: Q43.3, Q44.3, Q331.1, Q332.1, Q583.1, Q585.1, Q639.1, Q641.1, Q877.1, Q879.1, Q961.1, Q963.1
/Sheet6049469B/Q2: Q49.3, Q50.3, Q280.1, Q282.1, Q301.1, Q302.1, Q457.1, Q459.1, Q597.1, Q599.1, Q653.1, Q655.1, Q793.1, Q795.1, Q919.1, Q921.1, Q981.1, Q983.1
/Sheet6049469B/Q3: Q55.3, Q56.3, Q351.1, Q352.1, Q499.1, Q501.1, Q667.1, Q669.1, Q849.1, Q851.1, Q995.1, Q997.1
/Sheet6049469B/Q4: Q61.3, Q62.3, Q407.1, Q408.1, Q429.1, Q431.1, Q471.1, Q473.1, Q527.1, Q529.1, Q681.1, Q683.1, Q765.1, Q767.1, Q807.1, Q809.1, Q891.1, Q893.1, Q1009.1, Q1011.1
/Sheet6049469B/Q5: Q67.3, Q68.3, Q341.1, Q342.1, Q555.1, Q557.1, Q695.1, Q697.1, Q933.1, Q935.1, Q1023.1, Q1025.1
/Sheet6049469B/Q6: Q73.3, Q74.3, Q244.1, Q246.1, Q311.1, Q312.1, Q485.1, Q487.1, Q513.1, Q515.1, Q709.1, Q711.1, Q821.1, Q823.1, Q863.1, Q865.1, Q1037.1, Q1039.1
/Sheet6049469B/Q7: Q79.3, Q80.3, Q357.1, Q358.1, Q363.1, Q365.1, Q377.1, Q379.1, Q541.1, Q543.1, Q723.1, Q725.1, Q905.1, Q907.1, Q1051.1, Q1053.1
/Sheet6049469B/Q8: Q85.3, Q86.3, Q268.1, Q270.1, Q321.1, Q322.1, Q391.1, Q393.1, Q443.1, Q445.1, Q569.1, Q571.1, Q737.1, Q739.1, Q779.1, Q781.1, Q947.1, Q949.1, Q1065.1, Q1067.1
/Sheet6049469B/Sheet60506E58/sheet5E562435/A: Q37.1, Q38.1, Q39.3, Q41.3, Q42.3
/Sheet6049469B/sheet6050A891/sheet5E562435/A: Q85.1, Q86.1, Q87.3, Q89.3, Q90.3
/Sheet6049469B/sheet60509B33/sheet5E562435/A: Q61.1, Q62.1, Q63.3, Q65.3, Q66.3
/Sheet6049469B/sheet60509B34/sheet5E562435/A: Q67.1, Q68.1, Q69.3, Q71.3, Q72.3
/Sheet6049469B/sheet60509B35/sheet5E562435/A: Q73.1, Q74.1, Q75.3, Q77.3, Q78.3
/Sheet6049469B/sheet60509B36/sheet5E562435/A: Q79.1, Q80.1, Q81.3, Q83.3, Q84.3
/Sheet6049469B/sheet605078C4/sheet5E562435/A: Q43.1, Q44.1, Q45.3, Q47.3, Q48.3
/Sheet6049469B/sheet60508995/sheet5E562435/A: Q49.1, Q50.1, Q51.3, Q53.3, Q54.3
/Sheet6049469B/sheet60508996/sheet5E562435/A: Q55.1, Q56.1, Q57.3, Q59.3, Q60.3
/Sheet60494411/Sheet604ADE57/sheet6054A98B/sheet5E562435/A: Q965.1, Q966.1, Q967.3, Q969.3, Q970.3
/Sheet60494411/sheet606FAE28/Block: Q965.3, Q966.3, Q982.1, Q984.1, Q989.1, Q990.1
/Sheet60494411/sheet606FAE28/sheet6054A98B/sheet5E562435/A: Q985.1, Q986.1, Q987.3, Q989.3, Q990.3
/Sheet60494411/sheet606FDE93/Block: Q985.3, Q986.3, Q996.1, Q998.1, Q1003.1, Q1004.1
/Sheet60494411/sheet606FDE93/sheet6054A98B/sheet5E562435/A: Q999.1, Q1000.1, Q1001.3, Q1003.3, Q1004.3
/Sheet60494411/sheet60700FC2/Block: Q999.3, Q1000.3, Q1010.1, Q1012.1, Q1017.1, Q1018.1
/Sheet60494411/sheet60700FC2/sheet6054A98B/sheet5E562435/A: Q1013.1, Q1014.1, Q1015.3, Q1017.3, Q1018.3
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

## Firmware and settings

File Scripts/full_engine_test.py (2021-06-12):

import Utils.board as board
from Engines.EngineError import EngineError
import copy
import sys
from Utils.select_engine import select_engine


def engine_test(engine, b, turn, history, logging):
    # Check if game is over
    if b.game_over():
        logging['finished'] += 1
        if b.game_state() == 1:
            logging['loss'] += 1
            logging['loss_hist'].append(history)
            print('Error, Engine lost:' + history)
            print(b)
        else:
            logging['success'] += 1
        return

    if turn == 1:
        # Player's turn, iterate through all possible moves:
        moves = board.line_list_empty_index(b.board)

        if len(moves) == 0:
            raise Exception("can't play anymore:" + history)

        for move in moves:
            # Keep iterating:
            new_b = copy.deepcopy(b)
            new_b.set_i(move, 1)
            move_hist = "P1\\" + str(move)
            engine_test(engine, new_b, 2, history + " " + move_hist, logging)

    else:
        # Engine's turn:

        # Let engine determine move:
        try:
            move = engine.respond(b, 2)
        except EngineError:
            print('Gamestate: '+history)
            logging['error'] += 1
            logging['error_hist'].append(history)
            return

        # Make sure that is a legal move:
        if b.get_i(move) != 0:
            logging['error'] += 1
            logging['error_hist'].append(history)
            print('Error, Illegal engine move after this state:' + history)
            return

        # Keep iterating:
        new_b = copy.deepcopy(b)
        new_b.set_i(move, 2)
        move_hist = "P2\\" + str(move)
        engine_test(engine, new_b, 1, history + " " + move_hist, logging)

    return


def main():
    engine = select_engine(sys.argv)
    engine.open()
    try:
        log = {
            'finished': 0,
            'success': 0,
            'loss': 0,
            'loss_hist': [],
            'error': 0,
            'error_hist': []
        }

        # Test with player starting:
        print('Testing with player starting....')
        b = board.board()
        engine_test(engine, b, 1, "", log)

        print('Testing with engine starting....')
        # Test with engine starting:
        b = board.board()
        engine_test(engine, b, 2, "", log)

        print()
        print()
        print('====== Finished ======')
        print()
        print()

        if log['loss'] != 0 or log['error'] != 0:
            print('Error states:')
            print()
            for state in (log['error_hist']):
                print(state)

            print()
            print('Loss states:')
            print()
            for state in (log['loss_hist']):
                print(state)

            print()
            print()
            print('====== Summary ======')
            print()
            print()

        print('Finished Games: ' + str(log['finished']))
        print('Engine Win/Draw: ' + str(log['success']))
        print('Engine Loss: ' + str(log['loss']))
        print('Engine Error: ' + str(log['error']))

    finally:
        engine.close()


if __name__ == '__main__':
    main()

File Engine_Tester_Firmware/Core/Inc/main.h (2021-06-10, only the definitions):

#define LED1_Pin GPIO_PIN_0
#define LED1_GPIO_Port GPIOA
#define UART_TX_Pin GPIO_PIN_2
#define UART_TX_GPIO_Port GPIOA
#define UART_RX_Pin GPIO_PIN_3
#define UART_RX_GPIO_Port GPIOA
#define ENGINE_OUT_0_Pin GPIO_PIN_4
#define ENGINE_OUT_0_GPIO_Port GPIOA
#define ENGINE_OUT_1_Pin GPIO_PIN_5
#define ENGINE_OUT_1_GPIO_Port GPIOA
#define ENGINE_OUT_2_Pin GPIO_PIN_6
#define ENGINE_OUT_2_GPIO_Port GPIOA
#define ENGINE_OUT_3_Pin GPIO_PIN_7
#define ENGINE_OUT_3_GPIO_Port GPIOA
#define ENGINE_OUT_4_Pin GPIO_PIN_8
#define ENGINE_OUT_4_GPIO_Port GPIOA
#define ENGINE_OUT_5_Pin GPIO_PIN_9
#define ENGINE_OUT_5_GPIO_Port GPIOA
#define ENGINE_OUT_6_Pin GPIO_PIN_10
#define ENGINE_OUT_6_GPIO_Port GPIOA
#define ENGINE_OUT_7_Pin GPIO_PIN_11
#define ENGINE_OUT_7_GPIO_Port GPIOA
#define ENGINE_OUT_8_Pin GPIO_PIN_12
#define ENGINE_OUT_8_GPIO_Port GPIOA
#define OUT_CLK_Pin GPIO_PIN_3
#define OUT_CLK_GPIO_Port GPIOB
#define OUT_LATCH_Pin GPIO_PIN_4
#define OUT_LATCH_GPIO_Port GPIOB
#define OUT_DATA_Pin GPIO_PIN_5
#define OUT_DATA_GPIO_Port GPIOB

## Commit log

2020-02-14 Change AI ROM Output Encoding
    Change AI ROM Output Encoding
    Old Encoding Scheme enumerated the 9 possible Tic Tac Toe moves as binary numbers
    0 - 8, occupying the lower 4 bits of the 8 bit ROM.
    This however required some decode circuitry.
    The New encoding scheme maps each bit of the 8 bit ROM output to the first 8 slots of the Tic Tac Toe Board, and the 9th remaining slot to 0 (no bits active).
    This greatly reduces the number of gates and transistors needed to a single 9-input NOR gate to detect the 9th board slot.
    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
2020-02-20 Optimized Move-OK Circuitry to use approx 32 fewer Qs
2020-07-01 Setup KiCad Project
    [FetsAndCrosses.kicad_pcb, FetsAndCrosses.sch]
2020-07-01 First Draft
    [CPU.sch, Clock.sch, Col_Detect.sch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]
2020-07-01 Reworked everything to use Buses
    [CPU.sch, Clock.sch, Col_Detect.sch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]
2020-07-05 Schematic Done, Footprints assigned, ERC OK.
    [CPU.sch, Clock.sch, Col_Detect.sch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]
2020-07-05 Schematic fixes.
    [Clock.sch, Col_Detect.sch, Computer.sch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]
2020-07-05 PCB v0.0 done, production files generated.
    [FetsAndCrosses-B_Cu.gbr, FetsAndCrosses-B_Mask.gbr, FetsAndCrosses-B_Paste.gbr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]
2020-08-27 First Draft Schematic Updates
    [Clock.sch, Col_Detect.sch, Computer.sch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]
2020-08-27 Layout: Spacing done, 1 BoardCell ready
2020-08-27 First Layout draft done.
    [FetsAndCrosses-B_Cu.gbr, FetsAndCrosses-B_Mask.gbr, FetsAndCrosses-B_Paste.gbr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]
2020-08-28 Generated Production Files (v0.1)
    [FetsAndCrosses-B_Cu.gbr, FetsAndCrosses-B_Mask.gbr, FetsAndCrosses-B_Paste.gbr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]
2020-09-15 Fixed 'DRAW' Led in simulation.
2020-09-15 Updated Schematic
    - Fixed Mem cell
    - Fixed Draw LED to not light if last move wins game
    - Changed capacitor
    [Clock.sch, Col_Detect.sch, Computer.sch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]
2020-09-16 Updated PCB Layout
2020-09-16 Generated Production Files
    [FetsAndCrosses-B_Cu.gbr, FetsAndCrosses-B_Mask.gbr, FetsAndCrosses-B_Paste.gbr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]
2021-02-23 Added switch between engine/ROM
2021-03-06 PCB v1.0 layout mostly done.
    [Clock.sch, Computer.sch, FetsAndCrosses.sch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]
2021-03-06 Fixed Win-LEDs swapped.
    [FetsAndCrosses.sch, UI_GameState.sch]
2021-03-06 First Engine Draft
    [9x_Gate_NOT.sch, 9x_Gate_OR2in.sch, Cell1in.sch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]
2021-03-09 Finished layout draft of main PCB
    ERC is good, still need to check for via in pad (and silkscreen)
    [Computer.sch]
2021-03-31 Engine ready for validation+layout
    [9x_Gate_OR2in.sch, Engine.kicad_pcb, Engine.sch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]
2021-03-31 Changed to female connectors
    Layout finished, still need to do via-in-pad/silk checks
    [Computer.sch, Engine.kicad_pcb, Engine.sch]
2021-03-31 Small engine fix
    [Engine.sch]
2021-04-04 Engine Fixes
    [Cell1in.sch, Cell2in.sch, Cell3in.sch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]
2021-04-04 Ready for Engine Layout
    [Engine.kicad_pcb]
2021-04-04 Engine: pre Not-replication
    [Engine.kicad_pcb]
2021-04-04 Engine: Not Replicated
    [Engine.kicad_pcb]
2021-04-04 Engine: Pre 4in Nor replicate
    [Cell1in.sch, Engine.kicad_pcb, Engine.sch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]
2021-04-04 Engine: Post 4in nor replication
    [Engine.kicad_pcb]
2021-04-04 Engine: Pre 2in NOR replication
    [Engine.kicad_pcb]
2021-04-04 Engine: Post 2in NOR replication
    [Engine.kicad_pcb]
2021-04-04 Engine: Pre 2in OR replication
    [Engine.kicad_pcb]
2021-04-04 Engine: Post 2in OR replication
    [Engine.kicad_pcb]
2021-04-04 Engine: Pre 3-in Cell replication
    [Engine.kicad_pcb]
2021-04-04 Engine: Post 3-in cell replication
    [Engine.kicad_pcb]
2021-04-04 Engine: Pre 2in Cell replication
    [Engine.kicad_pcb]
2021-04-04 Engine: Post 2in Cell replication
    [Engine.kicad_pcb]
2021-04-04 Engine: Pre 1in Cell replication
    [Engine.kicad_pcb]
2021-05-09 Engine: Post 1in Cell replication
    [Engine.kicad_pcb]
2021-05-23 Engine layout.
    [Cell3in.sch, Engine.sch, EngineTest.kicad_pcb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]
2021-05-23 Generated main pcb v1.0 produciton files.
    [CPU.sch, Clock.sch, Col_Detect.sch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]
2021-05-23 Generated engine pcb production files.
    [9x_Gate_NOT.sch, 9x_Gate_OR2in.sch, Cell1in.sch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]
2021-05-23 Renamed to ECAD folder.
    [9x_Gate_NOT.sch, 9x_Gate_OR2in.sch, CPU.sch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]
2021-05-23 Engine test layout + production files v1.0
    [EngineTest.kicad_pcb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]
2021-05-31 Added PCB dimensions in KiCad
    [Engine_Test.kicad_pcb]
2021-09-05 Fixed off-by-one error in serial port selection
    [engine_hardware_bridge.py]
2022-02-06 POR, Tooling Holes
    [Clock.sch, Col_Detect.sch, Computer.sch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]
2022-02-06 Seperated Red/Green LEDs
    [FetsAndCrosses.sch, Gate_NOR2in.sch, UI_BoardLEDCell.sch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]
2022-02-06 Engine: Added Tooling Holes, LCSC Part numbers
    [Engine.sch, Gate_NOR2in.sch, Gate_NOR3in.sch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]
2022-02-06 Added Most LCSC Part Numbers
    [Clock.sch, Computer.sch, FetsAndCrosses.sch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]
2022-02-07 Generated Engine v1.1 Production Files
    [9x_Gate_NOT.sch, 9x_Gate_OR2in.sch, BOM.xlsx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]
2022-02-07 Specified LED Resisitors
    [UI_BoardLEDCell.sch, UI_GameState.sch, UI_Setup.sch]
2022-02-07 Generated v1.1 Production Files
    [BOM.xlsx, Clock.sch, Col_Detect.sch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]

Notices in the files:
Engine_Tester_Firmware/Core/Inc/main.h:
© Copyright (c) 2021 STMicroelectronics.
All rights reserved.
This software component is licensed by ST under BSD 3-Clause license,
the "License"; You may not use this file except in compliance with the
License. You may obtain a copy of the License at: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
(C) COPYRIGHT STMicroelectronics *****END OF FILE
